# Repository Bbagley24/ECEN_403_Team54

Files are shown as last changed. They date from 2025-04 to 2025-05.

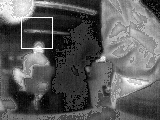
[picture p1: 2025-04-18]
website/websocket-streaming/output.png

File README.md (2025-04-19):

# **ECEN404-2025SP-Team-54**

This Repository contains all of the digital content created throughout the duration of Team 54's project. This includes the code made for the system, PCB plans and schematics, relevant presentations and documents, ect.**

- **Each subsytem has its own folder containing files and documents associated with the respective susbystem.**
- **Presentations are located in the "Presentations" folder and are organized by semester.**
- **Relevant documents are located in the "Documents and Reports" folder which is also organized by semester.**
- **All other content is stored in the "Miscellaneous" folder.**

## Overview

As industry demand grows, space inside medium voltage switchgear has become increasingly limited. Manufacturers are required to fit more devices and wires within the same limited space. Additionally, manufacturers are now being asked to include a remote viewing system within the switchgear to monitor a physical ground switch. This ground switch is physically blocked, by wires, from the view of the operator.

Our solution to this problem is to create a thermal remote viewing system that an operator can connect to through Wi-Fi, allowing for operators to confirm the grounding switch is either open or closed through video and automation. This will make switchgear operators jobs safer and more convenient.

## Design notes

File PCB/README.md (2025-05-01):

# PCB

This folder contains the Altium files used to fabricate the printed circuit boards for the system. This includes the schematics and PCB layouts for both the main board and the buck converters.
It also includes the file used to 3d print the case that protects the PCB.

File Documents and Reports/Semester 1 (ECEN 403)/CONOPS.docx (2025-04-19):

Remote Viewing within a High Voltage Apparatus

Blake Bagley, Julia Garcia, Erica Mathew

Concept of Operations

REVISION – Draft

14 September 2024

Concept of Operations

for

Remote Viewing within High Voltage Apparatus

Team <54>

Approved by:

_____________________________

Project Leader Date

_____________________________

Prof. Kalafatis Date

_____________________________

T/A Date

Change Record

Rev. | Date | Originator | Approvals | Description
- | 9/14/2024 | Remote Viewing within High Voltage Apparatus | | Draft Release

Table of Contents

List of Figures 4

1. Executive Summary 5

2. Introduction 5

2.1. Background 5

2.2. Overview 5

2.3. Referenced Documents and Standards 6

3. Operating Concept 6

3.1. Scope 6

3.2. Operational Description and Constraints 6

3.3. System Description 7

3.4. Modes of Operations 7

3.5. Users 7

3.6. Support 8

4. Scenario(s) 8

4.1. Ensuring State of Switchgear 8

5. Analysis 8

5.1. Summary of Proposed Improvements 8

5.2. Disadvantages and Limitations 9

5.3. Alternatives 9

5.4. Impact 9

List of Figures

Figure 1: Thermal Remote Viewing System Overview……………………….7

# 1. Executive Summary

As the industry demand grows, space within medium voltage switchgear has become increasingly limited. Manufacturers once had the luxury of allotting one device to a dedicated space, but now they must fit multiple apparatus for different functions into that same confined space. Manufacturers are additionally being asked to include safety devices within the switchgear. These safety devices are often not in areas that are easily accessible by the operator which makes visual inspection challenging. The goal of this project is to create a solution that enables operators to remotely view the safety devices inside the switchgear. This will significantly improve both safety and efficiency for the customer by providing continuous monitoring of the mechanical switches.

# 2. Introduction

This document is an introduction to our Proposed Thermal Remote Viewing System within High Voltage, a system capable of monitoring the mechanical safety switches within medium voltage switchgears. This project will allow operators to remotely confirm the state of the switchgear without putting themselves in danger.

## 2.1. Background

Currently, there is not a good system for monitoring the inside of a switchgear. Operators currently rely on a flashlight through a small window to get a view of the inside. This method is extremely inefficient because it provides very limited visibility and is unable to view regions that are covered by wires. This can also be very dangerous and can expose the operator to the dangers of high-voltage.

Our plan of creating a remote viewing system will allow operators to monitor the switchgear from a distance. Real time streaming with the use of thermal sensors will provide a comprehensive view of the switchgears. By placing thermal sensors close to the safety switches, we are able to get a visual representation of hard-to-reach areas.

## 2.2. Overview

Our system will be used to monitor safety switches within a medium voltage switchgear to check for gaps between contacts. We will use thermal sensors to create a temperature profile of the switchgear in real time. This raw thermal data from the sensor is sent to our microcontroller which converts the data into a video stream. Here we will have to perform linear interpolation to smooth the images. Our microcontroller would then send the processed data over a network via Wi–Fi. Finally we will create a website for the operators to easily interface with that displays the thermal video stream.

## 2.3. Referenced Documents and Standards

- IEEE Standard C37.20.2 IEEE Standard for Metal-Clad Switchgear
- IEEE Standard C37.04 IEEE Standard for Ratings and Requirement for AC High- Voltage Circuit Breakers with a Rated Maximum Voltage Above 1000V
- IEEE Standard C37.09 IEEE Standard Test Procedures for AC High-Voltage Circuit Breakers with Rated Maximum Voltage Above 1000 V
- ANSI C37.54 American National Standard for Alternating Current High-Voltage Circuit Breakers Applied in Metal-Enclosed Switchgear—Conformance Test Procedures
- NFPA 70E Standard for Electrical Safety in the Workplace
- NFPA 70 National Electrical Code

# 3. Operating Concept

## 3.1. Scope

The goal of this project is to create a system that allows for operators to remotely view a switch within a switchgear without opening it to ensure safe grounding. When an operator wants to see if the designated switch is open or closed, he/she will open a computer application that will connect to the microcontroller. A thermal image sensor will first capture a video of the designated switch; then the microcontroller will send that video to the application. One of the big constraints of this project is that we need to make sure that the dielectrics that are already in the switchgear still operate within industry standards. Due to budget constraints, the project will entail making this system for only one vertical tower of switchgear. We will still make this system expandable by having multiple towers connected to the application with their own dedicated sensors and microcontrollers. This system will help to make switchgear operators’ jobs much more safe and convenient.

## 3.2. Operational Description and Constraints

This system is intended to be used by switchgear operators to make sure switchgear can be safely operated. The operator should be able to open an application on a computer and connect to the switchgear he/she is operating on to see the desired switch’s state. An image will be taken by a thermal image system placed in the switchgear, which will then be sent to an application through a microcontroller for the operator to see. According to the sponsors of this project, the system must allow for the users to see the designated switch. Graphical representations are not enough for customers, and are not enough for operators to feel certain that the switchgear they are operating on is in the right state. The system must not cause the dielectrics to fail integrity tests because of the system’s addition to the switchgear. Also, no modifications will be made to the switchgear other than allowing for the ability to mount the system. The system is purely an addition to the switchgear.

## 3.3. System Description

There are three main parts of this system. The first part of this system is the thermal image sensor. This is what will create the image of the switch needed to be examined. The sensor will be placed within the switchgear at a respectful distance from the switch so that interference isn’t a problem. The second part of the system is the microcontroller. This part will configure the sensor, process the information read from the sensor, turn the information into something readable by an application, and send off the information through wi-fi. The final part of the system is an application that will take the information sent from the microcontroller and transform it into a viewable format for the operator. The system can be expanded upon by having more vertical towers connected to the application. Each vertical tower will have its own microcontroller and thermal image sensor to allow the application to connect to and view the inside of each tower.

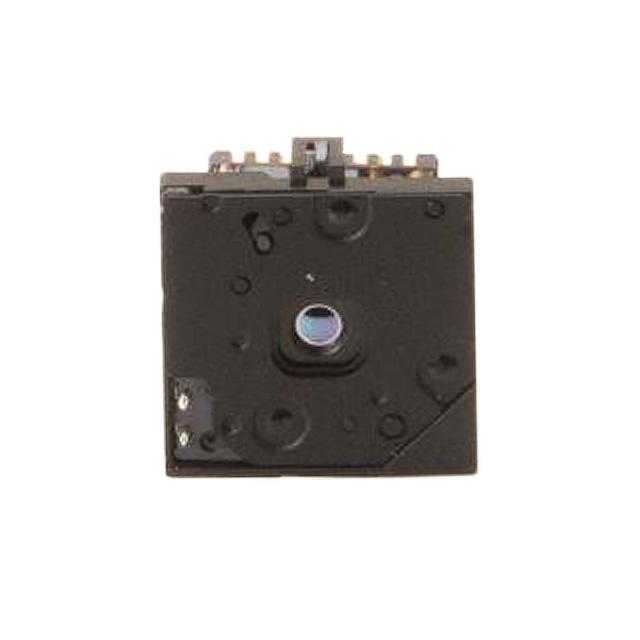
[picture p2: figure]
Figure 2
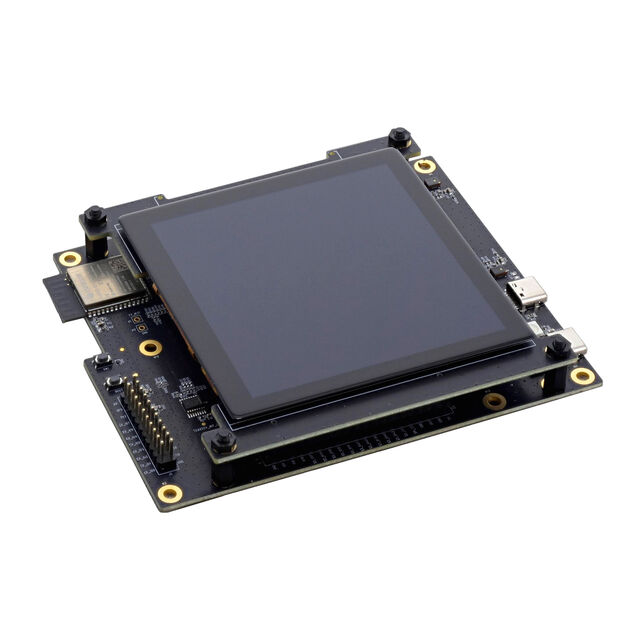
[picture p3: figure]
Figure 2
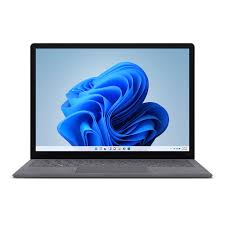
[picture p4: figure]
Figure 2

Figure 1: Thermal Remote Viewing System Overview

## 3.4. Modes of Operations

The operator only needs to view the switch through some type of produced image. The only difference between cases is that the switch might be located in a different part of the switchgear, which will cause the sensor to be placed in a new location. If this project were to be later expanded for the use of multiple towers, then this could entail the operator choosing which tower of switchgear to view.

## 3.5. Users

The users of this system, as stated throughout this report, will be switchgear operators. These operators are highly trained and knowledgeable of the hardware being observed by the proposed system. It is common for these users to have engineering and/or technical degrees. Thermal sensors are commonly used in procedures for switchgear, so operators should have some knowledge of how they work. Being that a big portion of these operators' jobs is maintenance and safety, our system will ensure that their job is much easier by giving the operator a good visualization of the state that the switchgear is in.

When it comes to the proposed system, there won't need to be any training for installation. The only training needed will probably be for the use of the application. The application should be simple to learn as it is supposed to be a tool for visualization.

## 3.6. Support

Support for our system will be given in the form of a manual on how to operate the system. It will detail the assembly of the system, configuration of the hardware, and operation of the application.

# 4. Scenario(s)

## 4.1. Ensuring State of Switchgear

The use of our thermal viewing system is to ensure the mechanical safety switches are open. If a maintenance worker needs to open up a switchgear and work inside, they can use our system to make sure it is depowered. The main problems with the switchgear are the density of electronics and lack of inner lighting. These issues make checking that the equipment is depowered extremely difficult. The operator cannot see the gaps from the window on the door, but our system will fix this. With a thermal image of the mechanical safety switches inside the switchgear, operators on the outside can visually see the open gaps, proving it is depowered and safe to open.

# 5. Analysis

## 5.1. Summary of Proposed Improvements

- The proposed system will make operating a switchgear much safer than it currently is. By having a thermal image sensor placed inside the switchgear, the system allows for the operator to not have to open up the back and check if the safety switch being observed is closed.
- The system will also utilize wi-fi which will make the switch observable at longer distances.
- The sensor can be remotely turned on and off, so the system is active only when needed by maintenance personnel. This ensures the system isn’t wasting any power.
- We could expand upon this project by making the system use machine learning. This will allow it to automatically classify switches as “open” or “closed”, which will improve the workflow for operators overseeing multiple switchgears.

## 5.2. Disadvantages and Limitations

Our proposed thermal viewing system will have some limitations which include:

- The size of the system is very limited due to the scant amount of space available within the switchgear.
- All equipment/components used in the system must be able to withstand high temperatures.
- The sensor and accompanying equipment must be shielded to ensure they don’t interfere with the dielectrics within the switchgear.
- The locations that the thermal sensor can be mounted are limited due to the space constraints within the switchgear.
- Due to budget constraints, the resolution of the picture won’t be very sharp.

## 5.3. Alternatives

Some alternatives to our proposed thermal viewing system are:

- Placing small flags behind the safety switches and using a flashlight to see inside a window on the front door of the switchgear. If the flag is visible, an operator can conclude the switches are open and the switchgear is depowered.
- Using a “normal” camera with a light source and streaming video of the switches to remote locations.
- A window placed on the backside of the switchgear closer to the mechanical safety switches. With this solution, the operator would need a light source of their own.

## 5.4. Impact

- There are no ethical concerns because the proposed system is being created to ensure the safety of anyone who works with switchgear. The system is intended to protect people at no cost to any other part of the overall switchgear.
- The environmental impact of our system is minimal. Our only impact comes from power consumption, which isn’t high.
- The impact for society would be minimal, as this wouldn’t affect the everyday lives of anyone except the operators that work directly with switchgear.

Concept of Operations Revision - Remote Viewing within High Voltage Apparatus

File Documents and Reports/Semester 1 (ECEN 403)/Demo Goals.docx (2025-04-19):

TEAM 54

Julia (PCB)

- Test #1: ESP32 Voltage

- Voltage will be read at the output of the buck converter that is wired to the ESP32.

- Criteria: The voltage read on the pcb by a multimeter will be within 5% of the simulations performed on WEBENCH.

- Test #2: VDDIO Voltage

- Voltage will be read at the output of the buck converter that is wired to the VDDIO pin of the camera.

- Criteria: The voltage read on the pcb by a multimeter will be within 5% of the simulations performed on WEBENCH.

- Test #3: VDDC Voltage

- Voltage will be read at the output of the buck converter that is wired to the VDDC pin of the camera.

- Criteria: The voltage read on the pcb by a multimeter will be within 5% of the simulations performed on WEBENCH.

- Test #4: VDD Voltage

- Voltage will be read at the output of the buck converter that is wired to the VDD pin of the camera.

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

- Test #5: Data Flow

- Using the oscilloscope, data flow will be read between the ESP32 and the camera.

- Criteria: There must be a waveform proving data is being transferred to the ESP32 from the camera.

Blake (Microcontoller)

- Test #1: WiFi Connection

- Microcontroller’s SSID will be seen over WiFi on any Laptop

- Test #2: Image Processing

- Example photo data will be processed to show accuracy

- Test #3: Receiving Image Data

- ESP-IDF command prompt will have a VoSPI packet printed in byte values to show accurate reception

Erica (Web Application)

- Test #1: Login Page/ Registration page

- When a user registers a new account it must show up in firebase. Incorrect login information should output an error message. Correct login information should direct the user to the overview page.

- Test #2: Overview page directs to correct “video stream”

- When the user clicks on a specific Model ID it should direct them to its respective video stream

- Test #3: Fetching Images

- Website properly fetches images in series and outputs the latest one at a rapid pace.

- Test #4: Drag and Drop UI works

- The user should be able to drag and drop boxes that represent the model IDs. When the user clicks on a specific box it should direct them to its respective video stream.

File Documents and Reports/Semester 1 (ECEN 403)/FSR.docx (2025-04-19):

Remote Viewing within a High Voltage Apparatus

Blake Bagley, Julia Garcia, Erica Mathew

Functional System Requirements

REVISION – Draft

24 September 2024

Functional System Requirements

for

Remote Viewing within a High Voltage Apparatus

Prepared by:

_____________________________

Author Date

Approved by:

_____________________________

Project Leader Date

_____________________________

John Lusher, P.E. Date

_____________________________

T/A Date

Change Record

Rev. | Date | Originator | Approvals | Description
- | 9/26/2024 | Remote Viewing within High Voltage Apparatus | | Draft Release

Table of Contents

Table of Contents III

List of Tables IV

No table of figures entries found. IV

List of Figures V

1. Introduction 5

1.1. Purpose and Scope 5

1.2. Responsibility and Change Authority 6

2. Applicable and Reference Documents 8

2.1. Applicable Documents 8

2.2. Reference Documents 8

2.3. Order of Precedence 9

3. Requirements 9

3.1. System Definition 9

3.2. Characteristics 10

3.2.1. Functional / Performance Requirements 10

3.2.2. Physical Characteristics 10

3.2.3. Electrical Characteristics 12

3.2.4. Environmental Requirements 13

3.2.5. Failure Propagation 13

4. Support Requirements 13

List of Tables

Table 1: Responsibilities ……………..……………………………………………………………..6

Table 2: Applicable Documents …………..………………………………………………………..8

Table 1: Reference Documents ………………………………..…………………………………..8

List of Figures

Figure 1. Conceptual Image……………………………………………………………………...6

Figure 2. Block Diagram of System…………………………………………………………..9

# 1. Introduction

## 1.1. Purpose and Scope

As industry demand grows, space inside medium voltage switchgear has become increasingly limited. Manufacturers are required to fit more devices and wires within the same limited space. Additionally, manufacturers are now being asked to include a remote viewing system within the switchgear to monitor a physical ground switch. This ground switch is physically blocked, by wires, from the view of the operator. Our project, Thermal Remote Viewing System within High Voltage, provides a real time visual depiction of the ground switch that an operator can view from a safe distance away from the switchgear. We will use a thermal sensor to create an image of the ground switch, which will then be sent to the microcontroller to process the information into a viewable format. The video information will then be sent to a web application for the operator to interface with. Our system will increase safety and efficiency for switchgear operators.

Figure 1. Conceptual Image

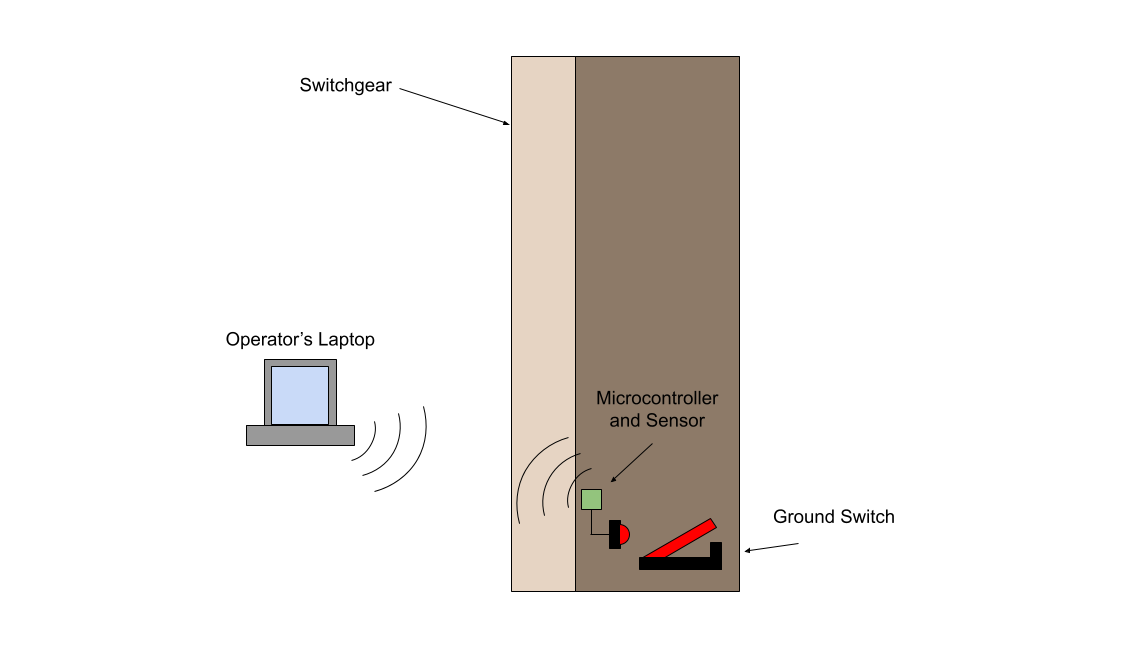
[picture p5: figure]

## 1.2. Responsibility and Change Authority

Erica Mathew will make sure all requirements detailed in the Functional System Requirements will be met. Requirements can only be changed if Erica and our sponsors at Powell Industries approve of the changes. Below are the responsibilities of everyone in the team.

Subsystem | Responsibility
Thermal Image Sensor | Julia Garcia
Microcontroller | Blake Bagley
Web Application | Erica Mathew

# 2. Applicable and Reference Documents

## 2.1. Applicable Documents

The following documents, of the exact issue and revision shown, form a part of this specification to the extent specified herein:

Document Number | Revision/Release Date | Document Title
IEEE Standard C37.20.2 | 2015-09-22 | IEEE Standard for Metal-Clad Switchgear
IEEE Standard C37.04 | 2019-05-31 | IEEE Standard for Ratings and Requirement for AC High- Voltage Circuit Breakers with a Rated Maximum Voltage Above 1000V
IEEE Standard C37.09 | 2019-04-11 | IEEE Standard Test Procedures for AC High-Voltage Circuit Breakers with Rated Maximum Voltage Above 1000 V
ANSI C37.54 | 2023 | American National Standard for Alternating Current High-Voltage Circuit Breakers Applied in Metal-Enclosed Switchgear—Conformance Test Procedures
NFPA 70E | 2024 | Standard for Electrical Safety in the Workplace
NFPA 70 | 2023 | National Electrical Code

## 2.2. Reference Documents

The following documents are reference documents utilized in the development of this specification. These documents do not form a part of this specification and are not controlled by their reference herein.

Document Number | Revision/Release Date | Document Title
1 | Version 1.9 | ESP32-S3 Series Datasheet
2 | Revision 204 | FLIR LEPTON® Engineering Datasheet
3 | 12/22/2020 | GlobTek, Inc. Li-Ion Polymer 3.7 V Battery Pack

## 2.3. Order of Precedence

In the event of a conflict between the text of this specification and an applicable document cited herein, the text of this specification takes precedence without any exceptions.

All specifications, standards, exhibits, drawings or other documents that are invoked as “applicable” in this specification are incorporated as cited. All documents that are referred to within an applicable report are considered to be for guidance and information only, except ICDs that have their relevant documents considered to be incorporated as cited.

# 3. Requirements

## 3.1. System Definition

The Thermal Remote Viewing System within High Voltage is a system specifically designed for remotely monitoring ground switches within a medium voltage switchgear. It allows operators to confirm a vertical tower is properly grounded before opening the switchgear. This system provides a real-time video stream of the ground switches which will be broadcasted to an online website. Our system consists of a thermal image sensor, microcontroller and a website.

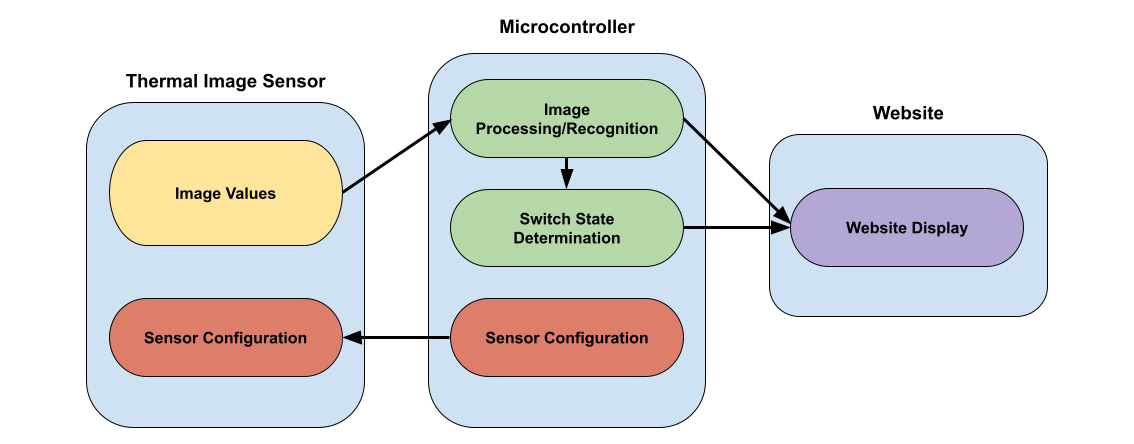
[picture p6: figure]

Figure 2. Block Diagram of System

There are three main components to this system. First block represents the first main component which is the thermal image sensor. This sensor will take in IR values and turn them into an image for the microcontroller to process. This sensor will need to be configured to be in the image format that will be used by the microcontroller.

The second block which is the microcontroller will use a machine learning algorithm to determine where the switch is located and another algorithm will be used for determining if the grounding switch is open or closed. The video and switch state will be then sent from the microcontroller to the website to be viewed by the operator.

## 3.2. Characteristics

### 3.2.1. Functional / Performance Requirements

#### 3.2.1.1. Connection to Website

The Thermal Remote Viewing System shall allow for multiple microcontrollers and thermal image sensors in different vertical towers to be connected to the website.

Rationale: This will allow for the operator to view multiple vertical towers.

#### 3.2.1.2. Machine Learning Error Rate

The Image Recognition and Switch State Determination done by the microcontroller shall not have an error rate exceeding 10%.

Rationale: This will allow for the machine learning of the microcontroller to perform as accurately as needed.

#### 3.2.1.3. Thermal Sensor Node Area

The thermal sensors should take a visual image that covers a minimum viewable area of 6x6 inches.

Rationale: This is a requirement specified by our customer to properly see the gap between contacts in the ground switches.

#### 3.2.1.4. Video Latency

The video output shall be a live video stream with no more than a 5 second delay.

Rationale: This is a requirement specified by our customer to properly view the gap between contacts in the ground switches.

#### 3.2.1.5. Video Resolution

The video output shall have a pixel resolution of 160x120 pixels

Rationale: This is the resolution of the thermal sensor we chose. This will allow for a clear image for the operator to observe.

### 3.2.2. Physical Characteristics

#### 3.2.2.1. Volume Envelope

The volume envelope of the Remote System shall be less than or equal to 6 inches in height, 6 inches in width, and 6 inches in length.

Rationale: This is a requirement specified by our customer due to constraints of the switchgear the system will be operating in

#### 3.2.2.2. Mounting

The thermal sensor should be mounted facing the ground switches to allow for a complete view. The mounting information shall be captured in the Remote Viewing System within High Voltage ICD.

Rationale: This is a requirement specified by our customer to provide a clear image to the operator.

#### 3.2.2.3. Installation

The installation information for The Thermal Remote Viewing System within High Voltage shall be provided to the customer through a user manual.

### 3.2.3. Electrical Characteristics

#### 3.2.3.1. Inputs

b. No inputs of the operator shall inhibit the function of The Thermal Remote Viewing System.

Rationale: By design, this should limit the risk of the system becoming damaged.

##### 3.2.3.1.1 Power Consumption

a. The maximum peak power of the system shall not exceed 3 watts.
b. For our class demonstration we will use a battery pack to power our system. If this system were to be adopted into a switchgear, it shall pull power from the switchgear itself.

Rationale: This is specified by the ESP32-S3 Series Datasheet and FLIR LEPTON® Engineering Datasheet.

##### 3.2.3.1.2 Input Voltage Level

The input voltage level for the Search and Rescue System shall be +3.7 VDC to +4.2 VDC.

Rationale: This is specified by GlobTek, Inc. Li-Ion Polymer 3.7 V Battery Pack Datasheet

#### 3.2.3.2. Outputs

##### 3.2.3.2.1 Data Output

The Thermal Remote Viewing System within High Voltage shall include an website interface compatible with the microcontroller to view the ground switch.

Rationale: The Thermal Remote Viewing System within High Voltage information passes directly to the customer’s system.

##### 3.2.3.2.2 Raw Video Output

The Thermal Remote Viewing System shall output a RAW14 video for the operator to view on the system’s website.

Rationale: This is a requirement specified in the FLIR LEPTON® Engineering Datasheet.

#### 3.2.3.3. Connectors

The Thermal Remote Viewing System within High Voltage shall follow the America National Standard for Electrical Connectors ANSI C119.6-2011.

Rationale: This is a requirement specified by in accordance with our battery

### 3.2.4. Environmental Requirements

The Thermal Remote Viewing System shall be designed to withstand and operate in the environments and laboratory tests specified in the following section.

Rationale: This is a requirement specified by our customer due to constraints of their system in which the The Thermal Remote Viewing System is integrating.

##### 3.2.4.1. Thermal Resistance

The Thermal Remote Viewing System should be able to properly operate in an environmental temperature up to 80C.

Rationale: This is a requirement specified in the FLIR LEPTON® Engineering Datasheet.

##### 3.2.4.1.1 Dielectrics Test

The Thermal Remote Viewing System shall not compromise the integrity of the dielectrics already within the switchgear

### 3.2.5. Failure Propagation

If the website doesn’t receive video input from the microcontroller after 30 seconds, the website shall display a notice that there is a problem connecting to the microcontroller.

Rationale: This will allow for the user to know if something is wrong with the system.

# 4. Support Requirements

The Thermal Remote Viewing System shall require internet connection and a computer in order to interact with the website application.

Functional System Requirements Revision - Remote Viewing within a High Voltage Apparatus

Functional System Requirements Revision - Project Name

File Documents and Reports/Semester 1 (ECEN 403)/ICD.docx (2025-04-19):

Remote Viewing within a High Voltage Apparatus

Blake Bagley, Julia Garcia, Erica Mathew

Interface Control Document

REVISION – Draft

26 September 2024

Interface Control Document

for

Remote Viewing within a High Voltage Apparatus

Prepared by:

_____________________________

Author Date

Approved by:

_____________________________

Project Leader Date

_____________________________

John Lusher II, P.E. Date

_____________________________

T/A Date

Change Record

Rev. | Date | Originator | Approvals | Description
- | 9/26/2024 | Blake Bagley, Julia Garcia, Erica Mathew | | Draft Release

Table of Contents

Table of Contents III

List of Tables IV

List of Figures V

1. Overview 6

2. References and Definitions 6

2.1. References 6

2.2. Definitions 6

2.3. Referenced Documents and Standards 6

3. Physical Interface 6

3.1. Weight 6

3.2. Dimensions 7

3.3. Mounting Locations 7

4. Thermal Interface 7

5. Electrical Interface 8

5.1. Primary Input Power 8

5.2. Voltage and Current Levels 8

5.3. Data Interfaces 9

5.4. User Control Interface 9

6. Communication/Device Interface 9

6.1. Wireless Communications 9

List of Tables

Table 1: Printed Circuit Board Weight……………………………………………………………..5

Table 2: Printed Circuit Board Dimensions………………………………………………………..6

Table 3: Maximum Voltage, Current and Power Levels………………………………………….7

Table 4: Nominal Voltage, Current and Power Levels…………………………………………...8

List of Figures

Figure 1: Electrical Interface Diagram………………………………………………………7

# 1. Overview

This document is provided to detail how the thermal sensor will interface with the microcontroller and how the microcontroller will interface with the website. It will list all inputs, outputs, and how the system manages each. An explanation of the inputs from the thermal sensor to the microcontroller will be provided. Then, an explanation of how that input will be transferred from the microcontroller to the website will follow.

# 2. References and Definitions

## 2.1. References

Refer to section 2.2 of the Functional System Requirements document.

## 2.2. Definitions

mA Milliamp

mW Milliwatt

g Grams

mm Millimeters

V Volts

TBD To Be Determined

# 3. Physical Interface

## 3.1. Weight

3.1.1. Entire Printed Circuit Board

Component | Weight | Number of Items | Total Weight
FLIR Lepton 3.5 Thermal Sensor | 0.91 g | 1 | 0.91 g
ESP32-S3 | TBD | 1 | TBD
Buck Converter Circuitry | TBD | 4 | TBD

Table 1: Printed Circuit Board Weight

## 3.2. Dimensions

### 3.2.1. Dimensions of Entire Printed Circuit Board

Component | Length | Width | Height
FLIR Lepton 3.5 Thermal Sensor | 12.7 mm | 11.5 mm | 6.835 mm
ESP32-S3 | 7 mm | 7 mm | 0.85 mm
Buck Converter Circuitry | TBD | TBD | TBD

Table 2: Printed Circuit Board Dimensions

## 3.3. Mounting Locations

The thermal sensor will be mounted facing the grounding switch at the back of the switchgear. The sensor must face the grounding switch because the switch is being viewed by the operator. It can only fit in the back due to space constraints within the switchgear.

# 4. Thermal Interface

The ESP-32 microcontroller will use a heat sink in order to prevent overheating and decreased efficiency. There is only one microcontroller in our system, so only one heat sink is needed. The thermal sensor has safeguards in place to prevent overheating.

# 5. Electrical Interface

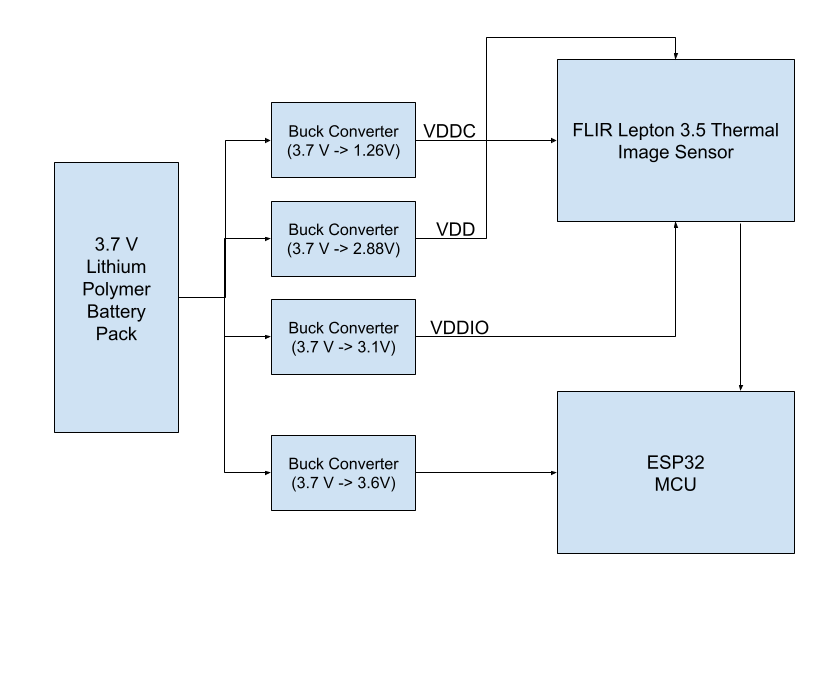
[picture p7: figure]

Figure 1: Electrical Interface Diagram

## 5.1. Primary Input Power

The system will be battery powered using a rechargeable 3.7 V lithium-ion polymer battery. When implemented into the switchgear, the system will be powered by the switchgear itself.

## 5.2. Voltage and Current Levels

### 5.2.1. Maximum Values

Component | Voltage [V] | Current [mA] | Power [mW]
FLIR Lepton 3.5 Thermal Sensor | 4.8 | 16 | 76.8
FLIR Lepton 3.5 Thermal Sensor Core | 1.5 | 110 | 165
FLIR Lepton 3.5 Thermal Sensor I/O | 4.8 | 310 | 1488
ESP32-S3 | 3.6 | 1500 | 3600

Table 3: Maximum Voltage, Current and Power Levels

### 5.2.2. Nominal Values

Component | Voltage [V] | Current [mA] | Power [mW]
FLIR Lepton 3.5 Thermal Sensor | 2.8 | 14 | 39.2
FLIR Lepton 3.5 Thermal Sensor Core | 1.2 | 84 | 100.8
FLIR Lepton 3.5 Thermal Sensor I/O | 3.1 | 235 | 728.5
ESP32-S3 | 3.3 | 500 | 1650

Table 4: Nominal Voltage, Current, and Power Levels

## 5.3. Data Interfaces

The thermal sensor will send raw video data to the microcontroller through serial pins (SPI), both the sensor and microcontroller are mounted to the PCB.

## 5.4. User Control Interface

The user control interface is a website that communicates with the microcontroller. The user will login using credentials provided through their companies. Then, the user will be able to select what switchgear vertical tower will be viewed. The user can select the desired video stream from the overview page or the user can use the search bar to find their desired video stream.

# 6. Communications / Device Interface Protocols

## 6.1. Wireless Communications

### 6.1.1. Wi-Fi

The microcontroller has a built-in WiFi module using IEEE 802.11b/g/n standards. This connection will be used to stream live video to the operator’s website.

Remote Viewing within a High Voltage Apparatus Revision -

Interface Control Document Revision - Remote Viewing within a High Voltage Apparatus

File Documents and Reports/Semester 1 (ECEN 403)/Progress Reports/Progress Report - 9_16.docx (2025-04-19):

Subsystem 1 - Julia (9/16)

- As a team we decided on the microcontroller and sensor we are using
  - Sensor: THERMAL IMAGE SENSOR 160HX120V
  - Microcontroller: ESP32
- Researched the viability of fiber optic cables to transfer data, not viable
- Researched how to encase the sensor and accompanying pcb, so the switchgear can pass the dielectric test.
  - A thin plastic material should work as it won’t interfere with the thermal sensor and isn’t metal
- Requested Altium access -> gained Altium access
- Created the github repository
- Researched possible power supplies, need at least 3.1 volts to power chosen sensor
  - GB20S05K01 - AC/DC CONVERTER 5V 15W ($8)
  - IRM-15-5 - Enclosed AC DC Converters 1 Output 5V 3A 85 ~ 305 VAC, 120 ~ 430 VDC Input ($9.28)
  - PAAM15-10 - Enclosed AC DC Converters 1 Output 5V 3A 90 ~ 264 VAC, 120 ~ 370 VDC Input ($20.59)
  - All three meet voltage requirements, PAAM has the best temperature rating with a max operating temp of 80 C, the other two have a max of 70 C.
    - Over double the price might not be worth only a 10 degree increase
- Researched how to plot a heatmap on matlab
  - https://www.mathworks.com/help/bioinfo/ref/heatmap.view.html
- Plan to order parts this week, so we can begin testing asap
- Set up Altium and start the subsystem project, goal is to finish
- For demo: Uart-usb then process in matlab

Subsystem 2-v

Subsystem 3-Erica (9/16)

- Started Researching website developments and built basic html layout that shows the video streaming feed
  - It currently displays an empty video and drop down to view different switchgear #’s
- Researching API for fetching videos
- Brainstorming new website features to be implemented:

Next steps:

- Make it look nice, put in powell colors/font
- Have login screen to input employee ID (requires database)
- Have search for switchgear serial code, once it pulls up it will display adjacent switchgears in drop down format (so operator does not have to retype code for switchgear right next to the original one)

9/23 Erica

- Completed Subsystem Introduction Project
- Continued working on Website UI design
- Met with company to discuss project requirements
- Started working on FSR and ICD

Blake (9/16)

* Dev microcontroller has been received

* Looking into frameworks and methods of ML to use

* Will probably use TensorFlow to identify the switch and use my own pixel math to determine if the switch is open or closed.

* More recently started on intro project

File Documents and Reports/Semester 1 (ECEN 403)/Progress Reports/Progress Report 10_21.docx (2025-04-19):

Erica:

Completed:

- Created a server using websockets to read images from a folder and outputs to a client (browser)
  - Using a 1000 image zip file the ‘video stream’ cycles through the images as it will with the microcontroller. Currently cycling as one image per second, but I will increase it.

Next Steps:

- Creating a ‘map page’ which is a buildable map for users to drag/drop blocks to match the physical layout of their switchgear setup.

Julia:

Completed:

- Finished the schematics for buck converters and overall pcb.

Next Steps:

- Currently routing the pcb, will be done by end of week
- Design review by end of week -> order the pcb

Blake:

Completed:

- Switch-State Determination done
- ESP32 can connect to devices through WiFi (very rough draft version)

Next Steps:

- Start coding for thermal sensor
- Create outline for image processing

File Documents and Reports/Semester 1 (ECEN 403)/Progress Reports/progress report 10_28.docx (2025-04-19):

Erica (out sick with excused absence):

Completed:

- Almost completed drag and drop buildable map **add image**
- Demo with 1000 image zip file is working

Next Steps:

- Clean up map, make it sleeker
- Add additional features to website

Julia:

Completed:

- Pcb is complete and ordered
- All parts not ordered have been acquired from the cage

Next Steps:

- Once it arrives begin soldering components and begin testing

Blake:

Completed:

- Have SPI communication set up for camera (not verified yet)

Next Steps:

- Test SPI communication
- Make SPI code turn a stream into a frame of data

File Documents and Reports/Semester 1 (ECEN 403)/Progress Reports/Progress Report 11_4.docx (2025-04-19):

Julia

- PCB arrived
- This week:
  - Start soldering

Blake

- VoSPI (data collection) is close to done, it is a little inaccurate with timing at times
- Still waiting on Powell to send photos to determine which rows and what temperatures to use for processing

This Week:

- Get code for processing image done (with or without photos)
- Efficiently storing data

Erica

- Finished drag/drop map
- This week:
  - Cleaning up functionality/look
  - Adding more features

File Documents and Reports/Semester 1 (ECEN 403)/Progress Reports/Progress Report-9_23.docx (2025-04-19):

9/23 Julia

- Chose power supply: 3.7 Lithium Polymer Battery Pack from GlobTek Inc.
- Order parts today (connectors, battery pack, enclosure material sheet and sensor)
- Finished block diagram for the circuits
- Start designing buck converters, need at least 4
  - VDDC pin for sensor (core voltage)
  - VDDIO pin for sensor (I/O voltage)
  - VDD pin for sensor (sensor voltage)
  - Input voltage for MCU
- Enclosure material chosen
  - UHMW (ultra-high molecular weight) polyethylene
  - Need to decide on thickness - can’t exceed 6 inches
    - Could have thinner piece where sensor points and thicker around the rest of the pcb

9/23 Erica

- Completed Subsystem Introduction Project
- Continued working on Website UI design
- Met with company to discuss project requirements
- Started working on FSR and ICD

Blake (9/23)

* Dev microcontroller has been received

* Looking into frameworks and methods of ML to use

* Will probably use TensorFlow to identify the switch and use my own pixel math to determine if the switch is open or closed.

* More recently started on intro project

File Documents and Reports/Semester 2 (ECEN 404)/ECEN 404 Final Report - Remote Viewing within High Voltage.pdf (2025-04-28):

## Remote Viewing Within High Voltage Apparatus

## Blake Bagley Julia Garcia Erica Mathew

# Remote Viewing Within High Voltage Apparatus Final Report

## Table of Contents

## Schedule and Validation 4

Concept of Operations | 7
Table of Contents | 10
List of Figures | 11

### 1. Executive Summary 12 2. Introduction 12 3. Operating Concept 13 4. Scenario(s) 15

5. Analysis | 16
Functional System Requirements | 18
Table of Contents | 21
List of Tables | 22
List of Figures | 23
6. Introduction | 24
7. Applicable and Reference Documents | 25
8. Requirements | 27
9. Support Requirements | 31
Interface Control Document | 30
Table of Contents | 35
List of Tables | 36
List of Figures | 37
10. Overview | 38

### 11. References and Definitions 38 12. Physical Interface 38 13. Thermal Interface 39 14. Electrical Interface 40

15.Communication/Device Interface 41

## Subsystem Reports 42

Table of Contents | 45
List of Figures | 46

### 16. Introduction 47 17. Thermal Sensor/PCB Subsystem Report 47

18.Microcontroller Subsystem Report | 52
19. Web Interface Subsystem Report | 61

## System Report 68

Table of Contents | 71
List of Figures | 72
20. Overview | 72
21.Development Plan and Execution 73 22.Conclusion 76

## Remote Viewing Within High Voltage Apparatus

## Blake Bagley Julia Garcia Erica Mathew

# Schedule and Validation

REVISION – 3
26 April 2025

Schedule

Validation

Test Name | Success Criteria | Methodology | Status | Engineers
Input Voltage | Voltage powering the PCB should be ~3.7 Volts. | Use multimeter to measure the DC voltage. | PASSED | Julia
Converter Voltage | Buck converter providing voltage should output ~3.3 Volts. | Use multimeter to measure the DC voltage. | PASSED | Julia
Board Communication | ESP32 should receive data from camera | Use oscilloscope to measure the data stream. | PASSED | Julia
Microcontroller connects to website | Website successfully received an HTTP POST request from the ESP32. | Checking the console log of both the website and microcontroller. | PASSED | Erica + Blake
Microcontroller sending image data | The website successfully received raw image data. | Checking console log on website and converting the raw image data to a png. | PASSED | Erica + Blake
Switch State Determination | The microcontroller should be able to identify the Switch State of a makeshift switch. | The microcontroller will monitor a box with a body heat source to demonstrate switch state determination. | PASSED | Blake
Dielectrics Test | The PCB should pass the dielectrics test and not cause any interference with the switchgear. | This will be tested at POWELL Industries. | PASSED | Julia
Switch State Determination Display | The website should be able to accurately display the Switch State Determination. | Switch State Determination with a makeshift switch. | PASSED | Erica + Blake
Website can load and display images in real time | The website should be able to display a few frames per second to mimic a slow video stream. | When the camera is running, the operator will monitor the latency on the website. | PASSED | Erica + Blake
Website is functioning as expected | The Login/Registration pages, Overview page, Map Builder page, and Video page are properly working. | The user will go through the components of the website and confirm it’s working properly. | PASSED | Erica

## Remote Viewing Within High Voltage Apparatus

## Blake Bagley Julia Garcia Erica Mathew

# Concept of Operations

REVISION – 3
26 April 2025

Concept of Operations
Remote Viewing within High Voltage Apparatus | Revision - 3

### CONCEPT OF OPERATIONS

### FOR

## Remote Viewing within High Voltage Apparatus

TEAM 54

APPROVED BY:

__________________________________
Project Leader | Date

__________________________________
Prof. Kalafatis | Date

__________________________________
T/A | Date

Concept of Operations

Change Record

Rev. | Date | Originator | Approvals | Description
1 | 12/5/2024 | Erica Mathew | | Draft Release
2 | 4/2/2025 | Julia Garcia | | April Update
3 | 4/26/2025 | Julia Garcia | | Final Release

Concept of Operations

Table of Contents

Table of Contents 10
List of Figures | 11
1. Executive Summary | 12
2. Introduction | 12
2.1. Background 12
2.2. Overview 12
2.3. Referenced Documents and Standards 13
3. Operating Concept | 13
3.1. Scope | 13
3.2. Operational Description and Constraints | 14
3.3. System Description | 14
3.4. Modes of Operation | 15
3.5. Users | 15
3.6. Support | 15
4. Scenarios(s) | 15
4.1. Ensuring State of Switchgear | 15
5. Analysis | 16
5.1. Summary of Proposed Improvements | 16
5.2. Disadvantages and Limitations | 16
5.3. Alternatives | 16
5.4. Impact | 17

Concept of Operations

List of Figures

Figure 1: Remote Thermal Viewing System Overview | 14

Concept of Operations

### 1. Executive Summary

As industry demand grows, space within medium voltage switchgear has become increasingly limited. Manufacturers once had the luxury of allotting one device to a dedicated space, but now they must fit multiple apparatus for distinct functions into that same confined space. Manufacturers are additionally being asked to include safety devices within the switchgear. These safety devices are often not in areas that are easily accessible by the operator which makes visual inspection challenging. The goal of this project is to create a solution that enables operators to remotely view the safety devices inside the switchgear. This will significantly improve both safety and efficiency for the customer by providing continuous monitoring of the mechanical switches.

### 2. Introduction

This document is an introduction to our Proposed Thermal Remote Viewing System within High Voltage, a system capable of monitoring the mechanical safety switches within medium voltage switchgears. This project will allow operators to remotely confirm the state of the switchgear without putting themselves in danger.

### 2.1. Background

Currently, there is not a good system for monitoring the inside of a switchgear. Operators currently rely on a flashlight through a small window to get a view of the inside. This method is extremely inefficient because it provides extremely limited visibility and is unable to view regions that are covered by wires. This can also be extremely dangerous and can expose the operator to the dangers of high voltage.
Our plan of creating a remote viewing system will allow operators to monitor the switchgear from a distance. Real time streaming with the use of thermal sensors will provide a comprehensive view of the switchgears. By placing thermal sensors close to the safety switches, we are able to get a visual representation of hard-to-reach areas.

### 2.2. Overview

Our system will be used to monitor safety switches within a medium voltage switchgear to check for gaps between contacts. We will use thermal sensors to create a temperature profile of the switchgear in real time. This raw thermal data from the sensor is sent to our microcontroller which converts the data into an image stream. Here we will have to perform linear interpolation to smooth the images. Our microcontroller would then send the processed data over a network via Wi-Fi. Finally, we will create a website for the operators to easily interface with that displays the thermal image stream.

Concept of Operations

### 2.3. Referenced Documents and Standards

- IEEE Standard C37.20.2 IEEE Standard for Metal-Clad Switchgear
- IEEE Standard C37.04 IEEE Standard for Ratings and Requirement for AC High-Voltage Circuit Breakers with a Rated Maximum Voltage Above 1000V
- IEEE Standard C37.09 IEEE Standard Test Procedures for AC High-Voltage Circuit Breakers with Rated Maximum Voltage Above 1000 V
- ANSI C37.54 American National Standard for Alternating Current High-Voltage Circuit Breakers Applied in Metal-Enclosed Switchgear—Conformance Test Procedures
- NFPA 70E Standard for Electrical Safety in the Workplace
- NFPA 70 National Electrical Code

### 3. Operating Concept

### 3.1. Scope

The goal of this project is to create a system that allows operators to remotely view a switch within a switchgear without opening it to ensure safe grounding. When an operator wants to see if the designated switch is open or closed, he/she will open a computer application that will connect to the microcontroller. A thermal image sensor will first capture an image of the designated switch; then the microcontroller will send that image to the application. One of the big constraints of this project is that we need to make sure that the dielectric integrity within the switchgear still meets industry standards. Due to budget constraints, the project will entail making this system for only one vertical tower of switchgear. We will still make this system expandable by having multiple towers connected to the application with their own dedicated sensors and microcontrollers. This system will help to make switchgear operators’ jobs much safer and more convenient.

Concept of Operations

### 3.2. Operational Description and Constraints

This system is intended to be used by switchgear operators to make sure switchgear can be safely operated. The operator should be able to open an application on a computer and connect to the switchgear he/she is operating on to see the desired switch’s state. An image will be taken by a thermal image system placed in the switchgear, which will then be sent to an application through a microcontroller for the operator to see.
According to the sponsors of this project, the system must allow the users to see the designated switch. Graphical representations are not enough for customers and are not enough for operators to feel certain that the switchgear they are operating on is in the right state. The system must not cause the dielectrics to fail integrity tests due to the system’s addition to the switchgear. Also, no modifications will be made to the switchgear other than allowing for the ability to mount the system. The system is purely an addition to the switchgear.

### 3.3. System Description

There are three main parts of this system. The first part of this system is the thermal image sensor. This is what will create the image of the switch needed to be examined. The sensor will be placed within the switchgear at a reasonable distance from the switch so that interference isn’t a problem. The second part of the system is the microcontroller. This part will configure the sensor, process the information read from the sensor, turn the information into something readable by an application, and send off the information through wi-fi. The final part of the system is an application that will take the information sent from the microcontroller and transform it into a viewable format for the operator. The system can be expanded upon by having more vertical towers connected to the application. Each vertical tower will have its own microcontroller and thermal image sensor to allow the application to connect to and view the inside of each tower.

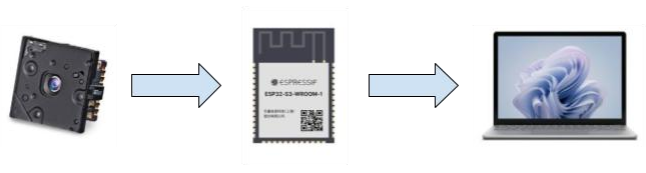
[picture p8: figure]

Figure 1: Remote Thermal Viewing System Overview

Concept of Operations

### 3.4. Modes of Operation

The operator only needs to view the switch through some type of produced image. The only difference between cases is that the switch might be located in a different part of the switchgear, which will cause the sensor to be placed in a new location. If this project were to be later expanded for use in multiple towers, then this could entail the operator choosing which tower of switchgear needs to view on the website.

### 3.5. Users

The users of this system, as stated throughout this report, will be switchgear operators. These operators are highly trained and knowledgeable of the hardware being observed by the proposed system. It is common for these users to have engineering and/or technical degrees. Thermal sensors are commonly used in procedures for switchgear, so operators should have some knowledge of how they work. Being that a substantial portion of these operators' jobs are maintenance and safety, our system will ensure that their job is much easier by giving the operator a good visualization of the state that the switchgear is in. When it comes to the proposed system, there won't need to be any training for installation. The only training needed will be for the use of the application. The application should be simple to learn as it is supposed to be a tool for visualization.

### 3.6. Support

Support for our system will be given in the form of a manual on how to operate the system. It will detail the assembly of the system, configuration of the hardware, and operation of the application.

### 4. Scenario(s)

### 4.1. Ensuring State of Switchgear

The use of our thermal viewing system is to ensure the mechanical safety switches are open. If a maintenance worker needs to open up a switchgear and work inside, they can use our system to make sure it is not powered. The main problems with the switchgear are the density of electronics and lack of inner lighting. These issues make checking that the equipment is depowered extremely difficult. The operator cannot see the gaps from the window on the door, but our system will fix this. With a thermal image of the mechanical safety switches inside the switchgear, operators on the outside can visually see the open gaps, proving it is depowered and safe to open.

Concept of Operations

### 5. Analysis

### 5.1. Summary of Proposed Improvements

- The proposed system will make operating a switchgear much safer than it currently is. By having a thermal image sensor placed inside the switchgear, it is no longer necessary for the operator to open the back of the switchgear to check the status of the safety switch.
- The system will also utilize wi-fi which will make the switch observable from longer distances.
- We could expand upon this project by making the system use machine learning. This will allow it to automatically classify switches as “open” or “closed,” which will improve the workflow for operators overseeing multiple switchgears.

### 5.2. Disadvantages and Limitations

Our proposed thermal viewing system will have some limitations which include:

- The size of the system is extremely limited due to the scant amount of space available within the switchgear.
- All equipment/components used in the system must be able to withstand high temperatures.
- The sensor and accompanying equipment must be shielded to ensure they don’t interfere with the dielectrics within the switchgear.
- The locations where the thermal sensor can be mounted are limited due to the space constraints within the switchgear.
- Due to budget constraints, the resolution of the picture won’t be very sharp.

### 5.3. Alternatives

Some alternatives to our proposed thermal viewing system are:

- Placing small flags behind the safety switches and using a flashlight to see inside a window on the front door of the switchgear. If the flag is visible, an operator can conclude the switches are open and the switchgear is depowered.
- Using a “normal” camera with a light source and streaming video of the switches to remote locations.
- A window placed on the backside of the switchgear closer to the mechanical safety switches. With this solution, the operator would need a light source of their own.

Concept of Operations

### 5.4. Impact

- There are no ethical concerns because the proposed system is being created to ensure the safety of anyone who works with switchgear. The system is intended to protect people at no cost to any other part of the overall switchgear.
- The environmental impact of our system is minimal. Our only impact comes from power consumption, which isn’t high.
- The societal impact would be minimal, as this would only affect the everyday lives of the operators that work directly with switchgear.

## Remote Viewing Within High Voltage Apparatus

## Blake Bagley Julia Garcia Erica Mathew

# Functional System Requirements

REVISION – 3
26 April 2025

Functional System Requirements

### FUNCTIONAL SYSTEM REQUIREMENTS

### FOR

## Remote Viewing within High Voltage Apparatus

TEAM 54

APPROVED BY:

__________________________________
Project Leader | Date

__________________________________
Prof. Kalafatis | Date

__________________________________
T/A | Date

Functional System Requirements

Change Record

Rev. | Date | Originator | Approvals | Description
1 | 12/5/2024 | Erica Mathew | | Draft Release
2 | 4/2/2025 | Julia Garcia | | April Update
3 | 4/26/2025 | Julia Garcia | | Final Release

Functional System Requirements

Table of Contents

Table of Contents 21
List of Tables | 22
List of Figures | 23
6. Introduction | 24
6.1. Purpose and Scope | 24
6.2. Responsibility and Change Authority | 25
7. Applicable and Reference Documents | 25
7.1. Applicable Documents | 25
7.2. Reference Documents | 25
7.3. Order of Precedence | 25
8. Requirements | 26
8.1. System Definition 26
8.2. Characteristics | 27
8.2.1 Functional/Performance Requirements | 27
8.2.1.1. Connection to Website | 28
8.2.1.2. Determination Accuracy | 28
8.2.1.3. Thermal Sensor Node Area | 28
8.2.1.4. Video Latency | 28
8.2.1.5. Image Resolution | 28
8.2.2 Physical Characteristics | 29
8.2.2.1. Volume Envelope | 29
8.2.2.2. Mounting | 29
8.2.2.3. Installation 29
8.2.3 Electrical Characteristics | 29
8.2.3.1. Inputs | 29
8.2.3.1.1. Power Consumption | 29
8.2.3.1.2. Input Voltage Level | 29
8.2.3.2. Outputs | 30
8.2.3.2.1. Data Output | 30
8.2.3.2.2. Image Output | 30
8.2.3.3. Connectors | 30
8.2.4 Environmental Requirements | 30
8.2.4.1. Thermal Resistance | 30
8.2.4.1.1. Dielectrics Test | 30
8.2.5 Failure Propagation | 31
9. Support Requirements | 31

Functional System Requirements

List of Tables

Table 1: Responsibilities | 25
Table 2: Applicable Documents | 25
Table 3: Reference Documents | 26

Functional System Requirements

List of Figures

Figure 2: Conceptual Image | 24
Figure 3: Block Diagram of System | 27

Functional System Requirements

### 6. Introduction

### 6.1. Purpose and Scope

As industry demand grows, space inside medium voltage switchgear has become increasingly limited. Manufacturers are required to fit more devices and wires within the same limited space. Additionally, manufacturers are now being asked to include a remote viewing system within the switchgear to monitor a physical ground switch. This ground switch is physically blocked, by wires, from the view of the operator. Our project, Thermal Remote Viewing System within High Voltage, provides a real time visual depiction of the ground switch that an operator can view from a safe distance away from the switchgear. We will use a thermal sensor to create an image of the ground switch, which will then be sent to the microcontroller to process the information into a viewable format. The image information will then be sent to a web application for the operator to interface with. Our system will increase safety and efficiency for switchgear operators.

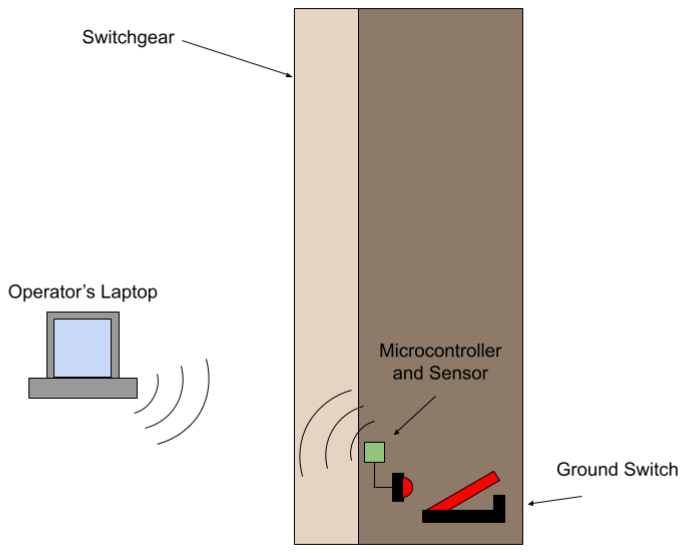
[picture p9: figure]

Figure 2: Conceptual Image

Functional System Requirements

### 6.2. Responsibility and Change Authority

Erica Mathew will make sure all requirements detailed in the Functional System Requirements will be met. Requirements can only be changed if Erica and our sponsors at Powell Industries approve of the changes. Below are the responsibilities of everyone in the team.

Subsystem | Responsibility
Thermal Image Sensor | Julia Garcia
Microcontroller | Blake Bagley
Web Application | Erica Mathew
Table 1: Responsibilities

### 7. Applicable and Reference Documents

### 7.1. Applicable Documents

The following documents, of the exact issue and revision shown, form a part of this specification to the extent specified herein:

Document Number | Revision/Release Date | Document Title
IEEE Standard C37.20.2 | 2015-09-22 | IEEE Standard for Metal-Clad Switchgear
IEEE Standard C37.04 | 2019-05-31 | IEEE Standard for Ratings and Requirement for AC High- Voltage Circuit Breakers with a Rated Maximum Voltage Above 1000V
IEEE Standard C37.09 | 2019-04-11 | IEEE Standard Test Procedures for AC High-Voltage Circuit Breakers with Rated Maximum Voltage Above 1000 V
ANSI C37.54 | 2023 | American National Standard for Alternating Current High-Voltage Circuit Breakers Applied in Metal-Enclosed Switchgear— Conformance Test Procedures
NFPA 70E | 2024 | Standard for Electrical Safety in the Workplace
NFPA 70 | 2023 | National Electrical Code
Table 2: Applicable Documents

Functional System Requirements

### 7.2. Reference Documents

The following documents are reference documents utilized in the development of this specification. These documents do not form a part of this specification and are not controlled by their reference herein.

Document Number | Revision/Release Date | Document Title
1 | Version 1.9 | ESP32-S3 Series Datasheet
2 | Revision 400 | FLIR LEPTON® Engineering Datasheet
3 | 12/22/2020 | GlobTek, Inc. Li-Ion Polymer 3.7V Battery Pack
4 | Version 2 | DS-16912-FLiR Lepton Breakout Board V2
5 | Revision 100 | Female_Headers.100_DS
Table 3: Reference Documents

### 7.3. Order of Precedence

In the event of a conflict between the text of this specification and an applicable document cited herein, the text of this specification takes precedence without any exceptions.
All specifications, standards, exhibits, drawings, or other documents that are invoked as “applicable” in this specification are incorporated as cited. All documents that are referred to within an applicable report are considered to be for guidance and information only, except ICDs that have their relevant documents considered to be incorporated as cited.

Functional System Requirements

### 8. Requirements

### 8.1. System Definition

The Thermal Remote Viewing System within High Voltage is a system specifically designed for remotely monitoring ground switches within a medium voltage switchgear. It allows operators to confirm a vertical tower is properly grounded before opening the switchgear. This system provides a real-time image stream of the grounding switch that will be broadcast to an online website. The system consists of a thermal image sensor, microcontroller, and a website.

Figure 3: Block Diagram of System
There are three main components to this system. The first block represents the first main component which is the thermal image sensor. This sensor will take in infrared values and turn them into an image for the microcontroller to process. This sensor will need to be configured to be in the image format that will be used by the microcontroller.
The second block, which is the microcontroller, will use an algorithm to determine where the switch is located and to determine if the grounding switch is open or closed. The image and switch state will be then sent from the microcontroller to the website to be viewed by the operator.

Functional System Requirements

### 8.2. Characteristics 8.2.1 Functional / Performance Requirements 8.2.1.1. Connection to Website

The Thermal Remote Viewing System shall allow for the microcontroller and thermal image sensor to be connected to the website.

Rationale: This will allow the operator to view multiple vertical towers.

### 8.2.1.2. Determination Accuracy

The Switch State Determination done by the microcontroller shall not have an error rate exceeding 10%.

Rationale: This will allow the machine learning of the microcontroller to perform as accurately as needed.

### 8.2.1.3. Thermal Sensor Node Area

The thermal sensors should take a visual image that covers a minimum viewable area of 6x6 inches.

Rationale: This is a requirement specified by our customer to properly see the gap between contacts in the ground switches.

### 8.2.1.4. Video Latency

The website should output images frame by frame to mimic a slow video stream.

Rationale: This is a requirement specified by our customer to properly view the gap between contacts in the ground switches.

### 8.2.1.5. Image Resolution

The image output shall have a pixel resolution of 160x120 pixels.

Rationale: This is the resolution of the thermal sensor chosen. This will allow for a clear image for the operator to observe.

Functional System Requirements

### 8.2.2 Physical Characteristics 8.2.2.1. Volume Envelope

The volume envelope of the Remote System shall be less than or equal to 6 inches in height, 6 inches in width, and 6 inches in length.

Rationale: This is a requirement specified by our customer due to constraints of the switchgear where the system will operate.

### 8.2.2.2. Mounting

The thermal sensor should be mounted facing the grounding switch to allow for a complete view. The mounting information shall be captured in the Remote Viewing System within High Voltage ICD.

Rationale: This is a requirement specified by our customer to provide a clear image for the operator.

### 8.2.2.3. Installation

The installation information for The Thermal Remote Viewing System within High Voltage shall be provided to the customer through a user manual.

### 8.2.3 Electrical Characteristics 8.2.3.1. Inputs

No inputs of the operator shall inhibit the function of The Thermal Remote Viewing System.

Rationale: By design, this should limit the risk of the system becoming damaged.

### 8.2.3.1.1. Power Consumption

The maximum peak power of the system shall not exceed 3 watts.
For our class demonstration we will use a battery pack to power our system. If this system were to be added into a switchgear, it shall pull power from the switchgear itself.

Rationale: This is specified by the ESP32-S3 Series Datasheet and FLIR LEPTON® Engineering Datasheet.

### 8.2.3.1.2. Input Voltage Level

The input voltage level for the Search and Rescue System shall be +3.7 VDC to +4.2 VDC.

Rationale: This is specified by GlobTek, Inc. Li-Ion Polymer 3.7 V Battery Pack Datasheet.

Functional System Requirements

### 8.2.3.2. Outputs 8.2.3.2.1. Data Output

The Thermal Remote Viewing System within High Voltage shall include a website interface compatible with the microcontroller to view the ground switch.

Rationale: The Thermal Remote Viewing System within High Voltage information passes directly to the customer’s system.

### 8.2.3.2.2. Image Output

The Thermal Remote Viewing System shall output an 8-bit grayscale image stream for the operator to view on the system’s website.

Rationale: This is a requirement specified in the FLIR LEPTON® Engineering Datasheet.

### 8.2.3.3. Connectors

The Thermal Remote Viewing System within High Voltage shall follow the America National Standard for Electrical Connectors ANSI C119.6-2011.

Rationale: This is a requirement specified in accordance with our battery.

### 8.2.4 Environmental Requirements

The Thermal Remote Viewing System shall be designed to withstand and operate in the environments and laboratory tests specified in the following section.

Rationale: This is a requirement specified by our customer due to constraints of the switchgear where the system will operate.

### 8.2.4.1. Thermal Resistance

The Thermal Remote Viewing System should be able to properly operate in an environmental temperature up to 80° C.

Rationale: This is a requirement specified in the FLIR LEPTON® Engineering Datasheet.

### 8.2.4.2. Dielectrics Test

The Thermal Remote Viewing System shall not compromise the integrity of the dielectrics already within the switchgear.

Rationale: This is a requirement specified by our customer due to constraints of the switchgear where the system will operate.

Functional System Requirements

### 8.2.5 Failure Propagation

If the website doesn’t receive image input, the website shall display a notice that the ‘Server is Down’.

Rationale: This will allow the user to know if something is wrong with the system.

### 9. Support Requirements

The Thermal Remote Viewing System shall require internet connection and a computer in order to interact with the website application.

## Remote Viewing Within High Voltage Apparatus

## Blake Bagley Julia Garcia Erica Mathew

# Interface Control Document

REVISION – 3
26 April 2025

Interface Control Document

### INTERFACE CONTROL DOCUMENT

### FOR

## Remote Viewing within High Voltage Apparatus

TEAM <54>

APPROVED BY:

__________________________________
Project Leader | Date

__________________________________
Prof. Kalafatis | Date

__________________________________
T/A | Date

Interface Control Document

Change Record

Rev. | Date | Originator | Approvals | Description
1 | 12/5/2024 | Erica Mathew | | Draft Release
2 | 4/2/2025 | Julia Garcia | | April Update
3 | 4/26/2025 | Julia Garcia | | Final Release

Interface Control Document

Table of Contents

Table of Contents 35
List of Tables | 36
List of Figures | 37
10.Overview | 38
11.References and Definitions | 38
11.1. References 38
11.2. Definitions 38

### 12. Physical Interface 38

12.1. Weight 38
12.1.1 Weight of Printed Circuit Board Version 1 38 12.1.2 Weight of Printed Circuit Board Version 2 38 12.1.3 Weight of Complete System 38
12.2. Dimensions 39
12.2.1 Dimensions of Printed Circuit Board Version 1 39 12.2.2 Dimensions of Printed Circuit Board Version 2 39 12.2.3 Dimensions of Complete System 39
12.3. Mounting Locations 39
13. Thermal Interface | 39
14.Electrical Interface | 40
14.1. Primary Input Power | 40
14.2. Voltage and Current Levels | 40
14.2.1 Maximum Values | 40
14.2.2 Nominal Values | 41
14.3. Data Interface | 41
14.4. User Control Interface | 41
15.Communications / Device Interface Protocols | 41
15.1. Wireless Communication | 41
15.1.1 Wi-Fi | 41

Interface Control Document

List of Tables
Table 4: Original Printed Circuit Board Weight | 38
Table 5: Updated Printed Circuit Board Weight | 38
Table 6: System Weight | 38
Table 7: Original Printed Circuit Board Dimensions | 39
Table 8: Updated Printed Circuit Board Dimensions | 39
Table 9: System Dimensions | 39
Table 10: Maximum Voltage, Current and Power Levels | 40
Table 11: Nominal Voltage, Current and Power Levels | 40

Interface Control Document

List of Figures
Figure 4: Electrical Interface Diagram | 40

Interface Control Document

### 10. Overview

This document is provided to detail how the thermal sensor will interface with the microcontroller and how the microcontroller will interface with the website. It will list all inputs, outputs, and how the system manages each. An explanation of the inputs from the thermal sensor to the microcontroller will be provided. Then, an explanation of how that input will be transferred from the microcontroller to the website will follow.

### 11. References and Definitions

### 11.1. References

Refer to section 2.2 of the Functional System Requirements document.

### 11.2. Definitions

mA | Milliamp
mW | Milliwatt
g | Grams
mm | Millimeters
V | Volts

### 12. Physical Interface

### 12.1. Weight

| 12.1.1 Weight of Printed Circuit Board Version 1
Component | Weight [g] | Number of Items | Total Weight [g]
PCB without battery | 18.391 | 1 | 18.391
PCB with battery | 34.015 | 1 | 34.015
Table 4: Original Printed Circuit Board Weight

### 12.1.2 Weight of Printed Circuit Board Version 2

Component | Weight [g] | Number of Items | Total Weight [g]
PCB without battery | 13.737 | 1 | 13.737
PCB with battery | 29.361 | 1 | 29.361
Table 5: Updated Printed Circuit Board Weight

### 12.1.3 Weight of Complete System

Component | Weight [g] | Number of Items | Total Weight [g]
PCB inside the case, without battery | 54.737 | 1 | 54.737
PCB inside the case, with battery | 70.361 | 1 | 70.361

Table 6: System Weight

Interface Control Document

### 12.2. Dimensions 12.2.1 Dimensions of Printed Circuit Board Version 1

Component | Length [mm] | Width [mm] | Height [mm]
Original PCB | 66.929 | 51.435 | 10
Table 7: Original Printed Circuit Board Dimensions

### 12.2.2 Dimensions of Printed Circuit Board Version 2

Component | Length [mm] | Width [mm] | Height [mm]
Updated PCB | 66.929 | 42.545 | 37.5
Table 8: Updated Printed Circuit Board Dimensions

### 12.2.3 Dimensions of Complete System

Component | Length [mm] | Width [mm] | Height [mm]
Updated PCB inside the case | 77.47 | 58.04 | 59.06
Table 9: System Dimensions

### 12.3. Mounting Locations

The thermal sensor will be mounted at least 6 inches away from and facing the grounding switch at the back of the switchgear. The sensor must face the grounding switch because the operator is viewing the switch. It can only fit in the back due to space constraints within the switchgear.

### 13. Thermal Interface

The case protecting the system is made of ABS which is rated to withstand temperatures up to 95 °C.
The case has a window made of IR material to increase the accuracy of the sensor.

Interface Control Document

### 14. Electrical Interface

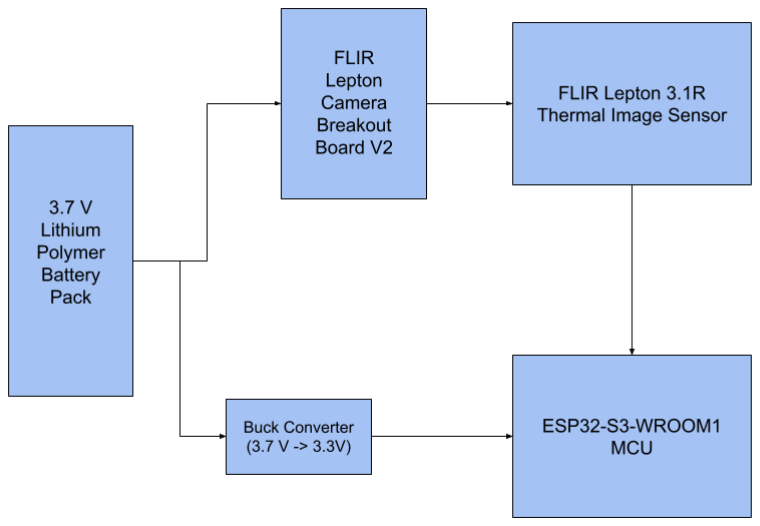
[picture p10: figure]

Figure 4: Electrical Interface Diagram

### 14.1. Primary Input Power

The system will be battery powered using a rechargeable 3.7 V lithium-ion polymer battery. When implemented into the switchgear, the system will be powered by the switchgear itself.

### 14.2. Voltage and Current Levels 14.2.1 Maximum Values

Component | Voltage [V] | Current [mA] | Power [mW]
FLIR Lepton 3.1R Thermal Sensor | 4.8 | 16 | 76.8
FLIR Lepton 3.1R Thermal Sensor Core | 1.5 | 110 | 165
FLIR Lepton 3.1R Thermal Sensor I/O | 4.8 | 310 | 1488
ESP32-S3-WROOM-1 | 3.6 | 1500 | 3600
Table 10: Maximum Voltage, Current, and Power Levels

Interface Control Document

### 14.2.2 Nominal Values

Component | Voltage [V] | Current [mA] | Power [mW]
FLIR Lepton 3.1R Thermal Sensor | 2.8 | 14 | 39.2
FLIR Lepton 3.1R Thermal Sensor Core | 1.2 | 84 | 100.8
FLIR Lepton 3.1R Thermal Sensor I/O | 3.1 | 235 | 728.5
ESP32-S3-WROOM-1 | 3.3 | 500 | 1650
Table 11: Nominal Voltage, Current, and Power Levels

### 14.3. Data Interface

The thermal sensor will send raw image data to the microcontroller through serial pins (SPI), the microcontroller is mounted to the PCB and the sensor is housed in the breakout board connected to the board.

### 14.4. User Control Interface

The user control interface is a website that communicates with the microcontroller. The user will login using credentials provided through their companies. Then, the user will be able to select what switchgear vertical tower will be viewed. The user can select the desired image stream from the overview page, or the user can use the search bar to find their desired image stream.

### 15. Communications / Device Interface Protocols

### 15.1. Wireless Communications 15.1.1 Wi-Fi

The microcontroller has a built-in Wi-Fi module using IEEE 802.11b/g/n standards. This connection will be used to stream live images to the operator’s website.

## Remote Viewing Within High Voltage Apparatus

## Blake Bagley Julia Garcia Erica Mathew

# Subsystem Reports

REVISION – 3
26 April 2025

Subsystem Reports
Remote Viewing within High Voltage Apparatus | Revision – 3

### SUBSYSTEM REPORTS

### FOR

## Remote Viewing within High Voltage Apparatus

TEAM 54

APPROVED BY:

__________________________________
Project Leader | Date

__________________________________
Prof. Kalafatis | Date

__________________________________
T/A | Date

Subsystem Reports
Remote Viewing within High Voltage Apparatus | Revision – 3
Change Record
Rev. | Date | Originator | Approvals | Description
1 | 12/5/2024 | Erica Mathew | | Draft Release
2 | 4/2/2025 | Julia Garcia | | April Update
3 | 4/26/2025 | Julia Garcia | | Final Release

Subsystem Reports
Remote Viewing within High Voltage Apparatus | Revision – 3
Table of Contents
Table of Contents 45
List of Figures | 46
16. Introduction | 47
17. Thermal Sensor/PCB Subsystem Report | 47
17.1. Subsystem Introduction | 47
17.2. Subsystem Details | 48
17.3. Subsystem Validation | 50
17.4. Subsystem Conclusion | 51
18. Microcontroller Subsystem Report | 52
18.1. Subsystem Introduction | 52
18.2. Subsystem Details | 52
18.3. Subsystem Validation | 55
18.4. Subsystem Conclusion | 60
19. Web Interface Subsystem Report | 61
19.1. Subsystem Introduction | 61
19.2. Subsystem Details | 61
19.2.1 Login/Registration Page | 61
19.2.2 Overview Page | 63
19.2.3 Map Builder Page | 63
19.2.3.1. Drag and Drop | 64
19.2.3.2. Saving and Loading | 64
19.2.3.3. Resetting Map | 64
19.2.3.4. Navigating to Video Page 64 19.2.4 Video Page 65
19.2.4.1. Server Side | 65
19.2.4.2. Video Page Front End | 66
19.3. Subsystem Validation | 66
19.3.1 Receiving Video | 66
19.3.2 Login System | 66
19.3.3 Search Bar | 67
19.3.4 Video Display Page 67
19.4. Subsystem Conclusion | 67

Subsystem Reports
Remote Viewing within High Voltage Apparatus | Revision – 3
List of Figures
Figure 5: Subsystem Breakdown | 47
Figure 6: Functional Block Diagram of the Thermal Sensor/PCB Subsystem | 48
Figure 7: Buck Converter Schematic for ESP32 Input | 48
Figure 8: ESP32-S3-WROOM-1 Connections | 49
Figure 9: PCB Layout | 49
Figure 10: ABS Plastic Case | 49
Figure 11: Results of ESP32 Buck Converter Shown by Multimeter | 50
Figure 12: ESP32 Buck Converter Output Voltage on Oscilloscope | 50
Figure 13: Data Stream Between the Sensor and Microcontroller on Oscilloscope | 51
Figure 14: Completed System Hardware | 51
Figure 15: Camera Communication Flowchart | 53
Figure 16: Normalization Equation | 53
Figure 17: Image Processing Flowchart | 54
Figure 18: Wi-Fi Connection (Laptop View) | 55
Figure 19: Wi-Fi Connection (PuTTY View) | 55
Figure 20: Segment ID Test | 56
Figure 21: Room Temperature Test | 57
Figure 22: Hand Temperature Test | 57
Figure 23: MATLAB Photo Test | 57
Figure 24: Makeshift Box for Testing | 58
Figure 25: Switch State Test (Closed) | 59
Figure 26: Switch State Test (Open) | 59
Figure 27: Website Communication Test (ESP_IDF) | 60
Figure 28: Website Communication Test (Website) | 60
Figure 29: Subsystem Block Diagram | 61
Figure 30: Login Page | 62
Figure 31: Registration Page | 62
Figure 32: Firebase Authentication | 62
Figure 33: Overview Page | 63
Figure 34: Map Builder Page | 63
Figure 35: Image Received by Website | 65
Figure 36: Raw Data to PNG | 65
Figure 37: Video Page | 66
Figure 38: Website Overview | 67

Subsystem Reports
Remote Viewing within High Voltage Apparatus | Revision – 3

### 16. Introduction

The first subsystem is the thermal sensor and PCB, the power supply is housed on the board along with the microcontroller. The thermal sensor is housed on the breakout board attached to the main PCB. All components are housed in an ABS plastic encasing. Below is the subsystem breakdown for our Thermal Remote Viewing System.

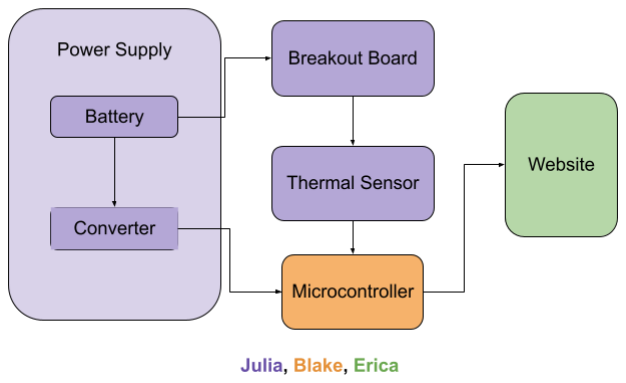
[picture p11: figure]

Figure 5: Subsystem Breakdown

### 17. Thermal Sensor/PCB Subsystem Report (Julia Garcia)

### 17.1. Subsystem Introduction

The thermal sensor/PCB is the subsystem that contains all the hardware of the system. This includes the power supply, the microcontroller, the camera module, and the ABS plastic encasing. For the power supply, a lithium-ion battery pack is connected to a buck converter to power the microcontroller and to the breakout board for the camera module. The microcontroller will be connected to the camera module through serial communication (SPI). The purpose of this subsystem is to provide power to both major components, ensure data transfer between them, and protect the system and the switchgear.
The breakout board replaced three buck converters that provided power to the camera module directly. The camera socket wasn’t able to be hand soldered while maintaining the functionality of the part. The breakout board adds height and weight to the overall system, but it reduces the size of the main board, and the number of parts needed. The breakout board attaches to the board with a connector and is removable, though this isn’t relevant to the operator because they don’t interact with the hardware.
The ABS plastic encasing protects the sensor from the high voltage of the switchgear and ensures the dielectric integrity within the switchgear is maintained.

Subsystem Reports
Remote Viewing within High Voltage Apparatus | Revision – 3

### 17.2. Subsystem Details

A block diagram of the subsystems is shown below.

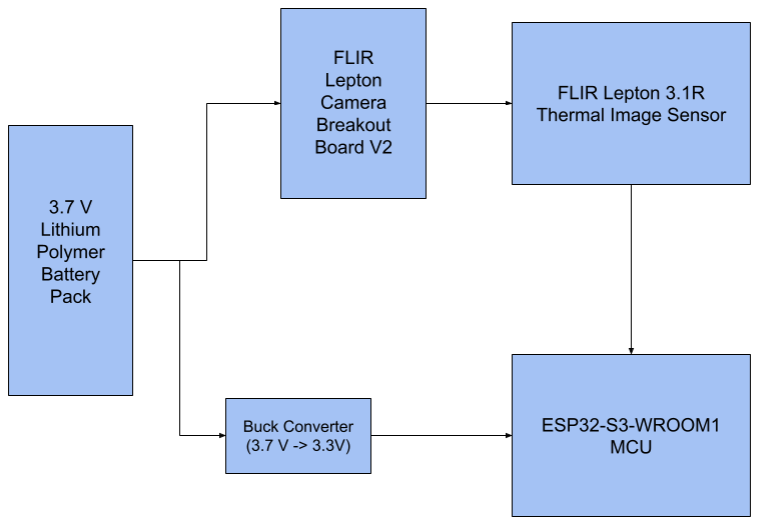
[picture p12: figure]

Figure 6: Functional Block Diagram of the Thermal Sensor/PCB Subsystem
The camera module needs three separate power inputs to operate. The core of the camera (VDDC), the sensor itself (VDD), and the input/output ring (VDDIO) all need to be powered separately. This is done by the breakout board that houses the camera socket. The microcontroller needs pull-down resistors and push-buttons to function and be programmed, while also needing to be powered. The SPI interface between the microcontroller and the camera module requires four pins on each device to be allocated in order for the data to transfer properly.
The layout of the buck converter is shown in the figure below.

Figure 7: Buck Converter Schematic for ESP32 Input

Subsystem Reports
Remote Viewing within High Voltage Apparatus | Revision – 3
The connections for the microcontroller are shown in the figure below.

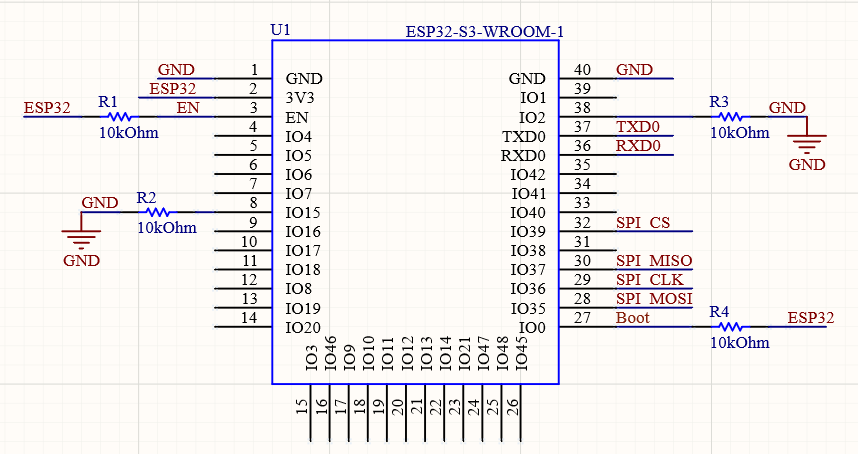
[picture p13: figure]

Figure 8: ESP-S3-WROOM-1 Connections
The overall layout of PCB is shown in the figure below.

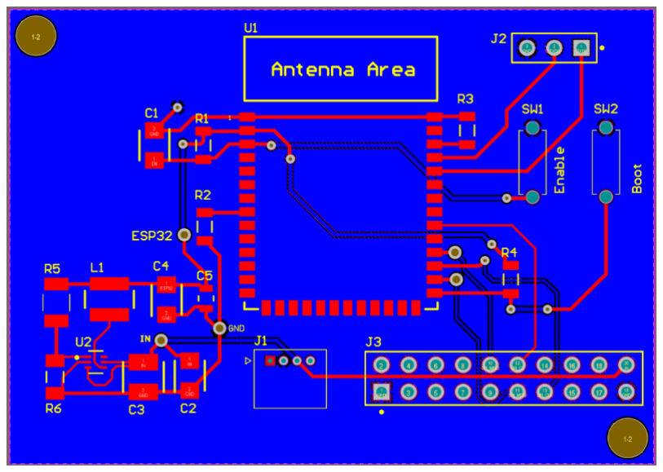
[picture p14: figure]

Figure 9: PCB Layout
The ABS plastic encasing is shown in the figure below.

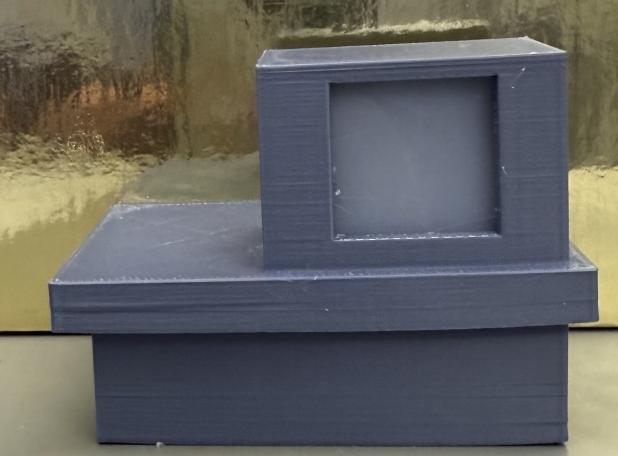
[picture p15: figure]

Figure 10: ABS Plastic Case

Subsystem Reports
Remote Viewing within High Voltage Apparatus | Revision – 3

### 17.3. Subsystem Validation

To validate the functionality of the PCB, the buck converter was tested with a multimeter to ensure the output value was within acceptable limits. The values on the data sheets of the components were nominal values, therefore slightly higher or lower would still power the components. The output was also tested with an oscilloscope to see if the DC voltage had an acceptable ripple.
The three figures below show the results of the buck converter, the input for the microcontroller, and the data stream between the sensor and microcontroller.

Figure 11: Results of ESP32 Buck Converter Shown by Multimeter

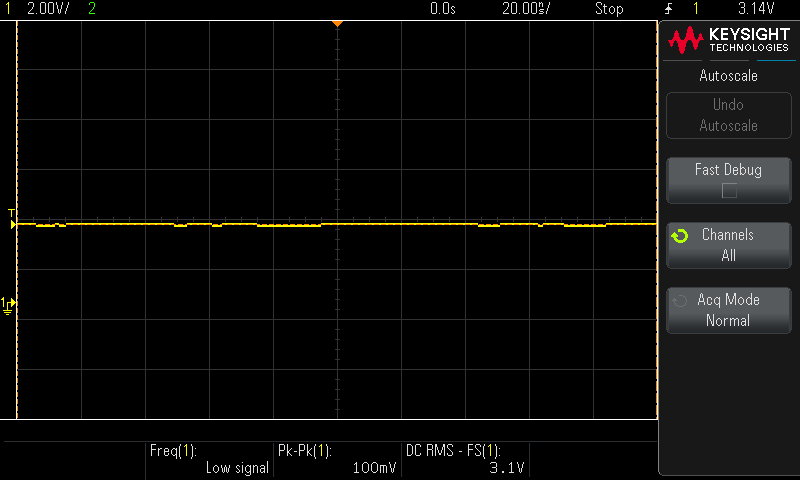
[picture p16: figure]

Figure 12 : ESP32 Buck Converter Output Voltage on Oscilloscope

Subsystem Reports
Remote Viewing within High Voltage Apparatus | Revision – 3

Figure 13: Data Stream Between the Sensor and Microcontroller on Oscilloscope

### 17.4. Subsystem Conclusion

The goal of this subsystem is to ensure the two major components can receive power and communicate with each other. The hardware of the system is what provides the images for the microcontroller to send and for the website to receive.
This subsystem was changed from one board with four buck converters, the microcontroller and the thermal sensor all mounted on it to a board with one buck converter, the microcontroller, and a connector with a breakout board, which houses the thermal sensor, attached. All four buck converters were functional, and the microcontroller was able to download code, but the camera socket wasn’t able to be hand soldered without losing functionality. This caused the change of the socket to be mounted directly to the board to the breakout board being separated and attached through a connector.
The subsystem is completely functional, the correct voltage level is provided to the breakout board and the microcontroller. The microcontroller is able to download and run the code provided by subsystem two (microcontroller). The thermal sensor and microcontroller communicate successfully which allows image data to be displayed by subsystem three (website).
The figure below shows the completed subsystem.

Figure 14: Completed System Hardware

Subsystem Reports
Remote Viewing within High Voltage Apparatus | Revision – 3

### 18. Microcontroller Subsystem Report (Blake Bagley)

### 18.1. Subsystem Introduction

This subsystem is made up of the microcontroller and the code that will be uploaded to it. As stated previously in this report, the microcontroller has three main jobs: Take the image data from the thermal image sensor and process the image to determine if the switch is open or closed and send both the image data and the determination to the website.

### 18.2. Subsystem Details

The microcontroller will first attempt to connect to the operator’s laptop. It does this by declaring itself as a station and sets a connection to the laptop’s hotspot. This hotspot will give the microcontroller the ability to access the website.
The next thing the microcontroller does is capture the image data from the thermal camera. To describe how the microcontroller takes in the data from the thermal imager, we first need to understand how the thermal imager is sending data. The Lepton 3.1R uses SPI communication to send its data. It does this by separating rows of pixel data into packets. Each packet consists of 80 pixels of data. Those packets are then separated into four different segments each containing 60 packets. Through SPI communication, the thermal imager will send one packet per falling edge of the chip select signal. Also, for each segment, the twentieth packet will have the ID of the segment that is currently being read. With all of this in mind, the following is how the microcontroller takes in the image data. First, the code will continuously read for valid packets until it reads a packet with an ID of zero. Then, it will start to store the packets into memory until the twentieth packet is read. If the segment number is invalid, the memory will be reset and the reading process from before will start again. If not, the segment will finish being read, and the code will restart the process of looking for the next segments until all segments are read and stored. Below is a flowchart to further describe the code snippet.

Subsystem Reports
Remote Viewing within High Voltage Apparatus | Revision – 3

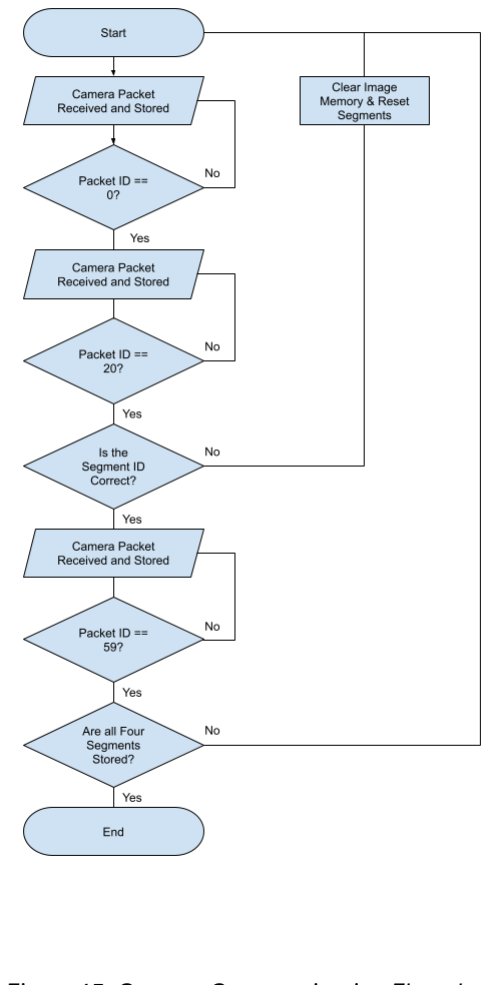
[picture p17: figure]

Figure 15: Camera Communication Flowchart
Next, the code will compress the image and process it to determine if the switch that the camera is fixed on is open or closed. It will do this by reading temperature differences between the entire frame and a smaller area of the frame in which the contact of the switch is located when the switch is closed. Firstly, the image data stored isn’t normalized at all, so it would be fairly difficult to do math that could read temperature differences. So, the code normalizes the pixel data to range from 0 to 255 using the equation below.
Tn = (ti − tmin) (

255

tmax − tmin

)

Figure 16: Normalization Equation

Tn = normalized temperatures ti = current temperature
tmax = maximum temperature tmin = minimum temperature

Subsystem Reports
Remote Viewing within High Voltage Apparatus | Revision – 3
This will also make the image data quicker to send to the website as well as provide a clearer image. Then the code will calculate the average temperatures of both areas and determine the switch’s state on whether the difference in the temperatures is high enough or not. If there is a significant difference, the microcontroller will determine that the switch is closed. The flowchart below further describes the code’s process.

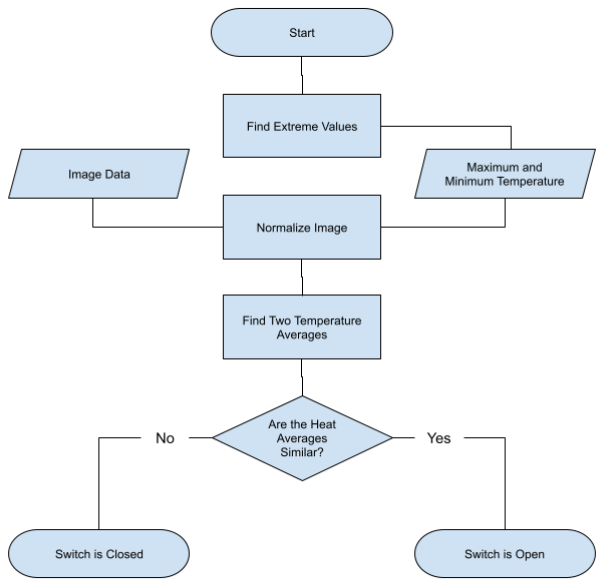
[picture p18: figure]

Figure 17: Image Processing Flowchart

Finally, the code will send the image data and the determination to the website. This is done by using HTTP post requests. The microcontroller will create a post request that has the image, and the determination stored in separate headers. In other words, it will configure an HTTP Client to connect to the website, set the post request, and then send it to the website. The code will then loop back to trying to read an image from the camera and keep looping.

Subsystem Reports
Remote Viewing within High Voltage Apparatus | Revision – 3

### 18.3. Subsystem Validation

To validate the Wi-Fi connection of the microcontroller, a laptop was used as a device for the microcontroller to connect to. It was specifically set for the microcontroller to connect to the laptop’s hotspot. The snapshots from the laptop and the ESP-IDF console below show that the Wi-Fi connection is made.

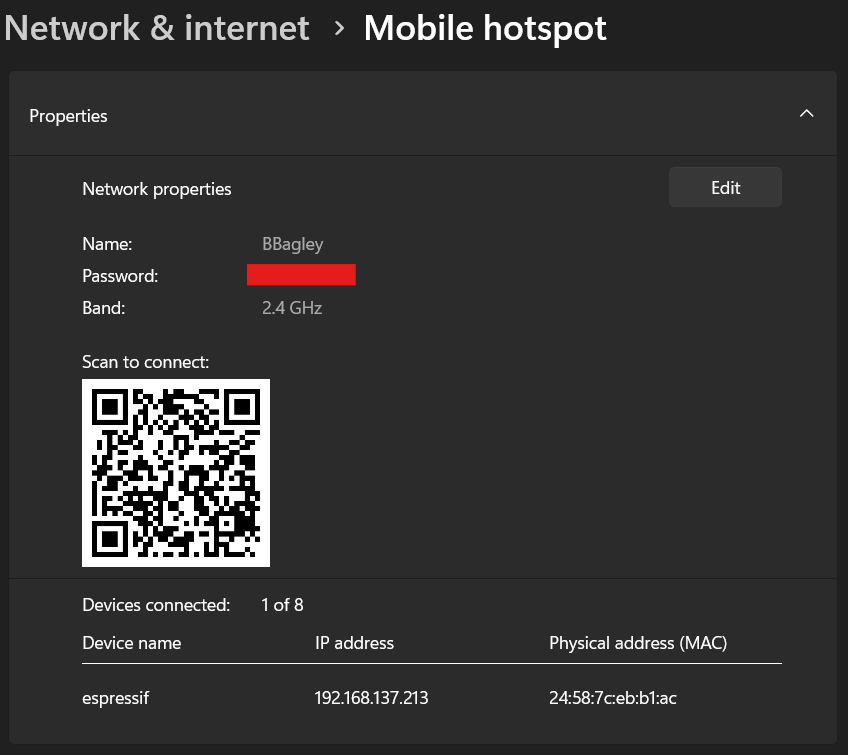
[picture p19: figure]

Figure 18: Wi-Fi Connection (Laptop View)

Figure 19: Wi-Fi Connection (PuTTY View)

Subsystem Reports
Remote Viewing within High Voltage Apparatus | Revision – 3
To validate the communication between the camera and the microcontroller, three tests were performed. The first test was to see if the pixel data was being stored in the correct order. This was done by having the code print the segment ID at the twentieth packet of each segment and then checking stored values to see if they aligned. The snapshot below shows that the code read through invalid segments until it finally got to the correct ones and stored them. The first number on the left represents the segment ID and the second number represents the packet ID. The segment ID should read in order as 1, 2, 3, and 4. However, when the data is read in, the numbers for the segment ID are shifted by 4 bits. Therefore, in the screenshot, they should read as 16, 32, 48, and 64. It also does a check to see if the packets were stored correctly by printing the ID of the twentieth packet of the stored data. The ID should be 16 if the data is stored correctly.

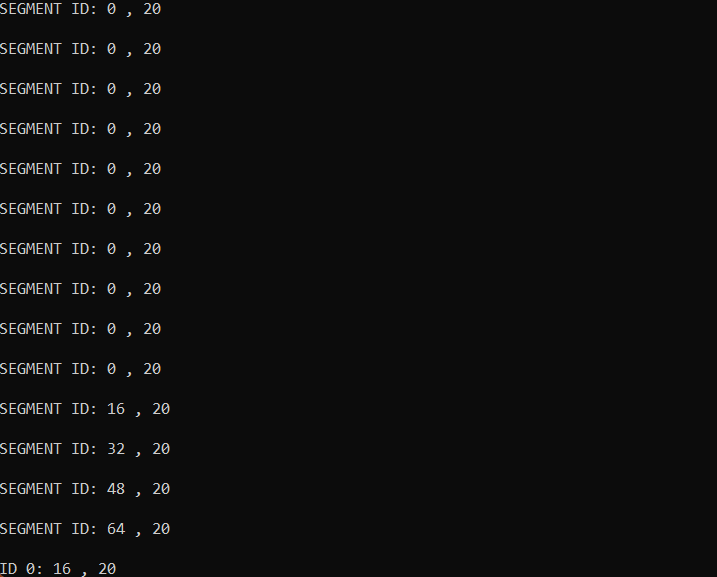
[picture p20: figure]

Figure 20: Segment ID Test
The second test checks if the code will ignore invalid frames. In the previous figure, it shows that the segments whose ID is 0 get skipped until a valid ID of 16, 32, 48, or 64 is read.
The next test is to check temperature reading to make sure they align with the temperature in front of the camera. This was done by putting two different heat readings in front of it. One of the temperature readings had nothing in front of the camera. The other had a hand fully covering the view of the camera.
There are two screenshots below. The first showing the first 10-pixel values of the camera when nothing is in frame and the second showing pixel values of the camera when a hand is in frame. The screenshots show that a higher pixel intensity is read when a hand is in front of the camera. Therefore, the microcontroller is correctly reading temperature increases and decreases from the camera.

Subsystem Reports
Remote Viewing within High Voltage Apparatus | Revision – 3

Figure 21: Room Temperature Test

Figure 22: Hand Temperature Test
Finally, it was tested by pulling the image data from the microcontroller and displaying it in MATLAB. The image below is of a desk showing that the microcontroller is receiving image data correctly.

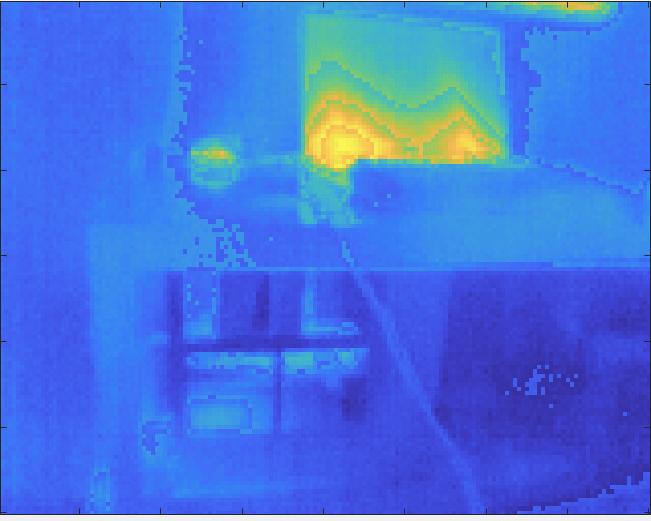
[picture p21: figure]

Figure 23: MATLAB Photo Test

Subsystem Reports
Remote Viewing within High Voltage Apparatus | Revision – 3
To validate the image processing, the code needed to be checked to ensure it was reading the temperature differences in the correct regions. The region of check should be located around the top left corner of the camera's sight. To test this, a makeshift switch was created, using a cardboard box that has two holes to mimic the positions of the real switch. One of the holes was located in the window of check and the other is located in the opposite corner. Below is a photo of the box.

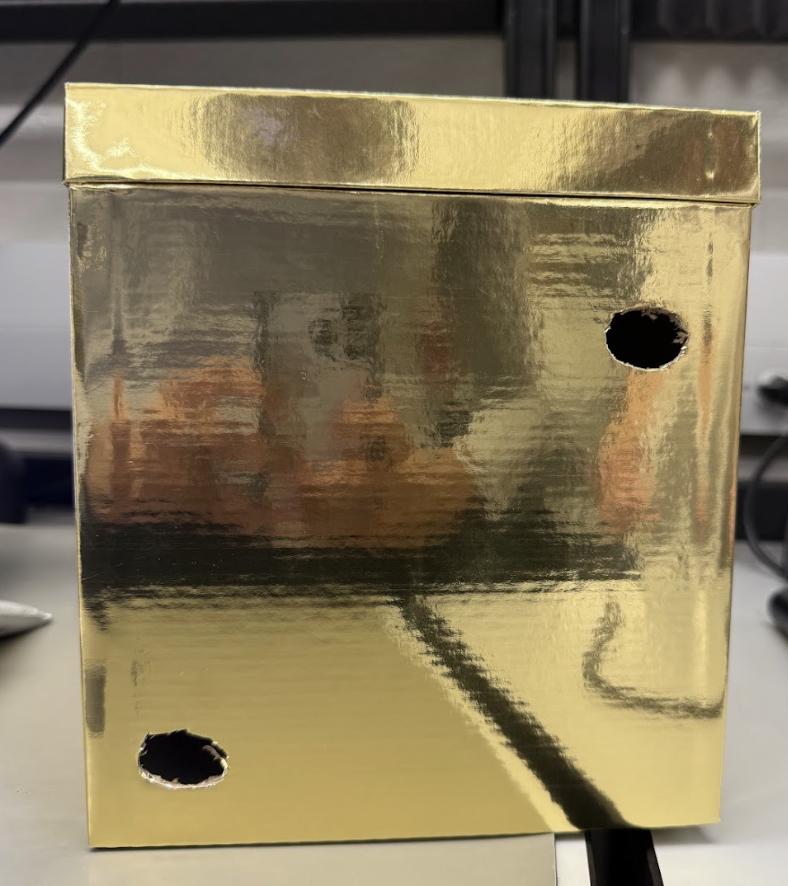
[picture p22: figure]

Figure 24: Makeshift Box for Testing

Subsystem Reports
Remote Viewing within High Voltage Apparatus | Revision – 3
While the system is running, if heat is read in the top hole, the microcontroller should output “Closed”, otherwise it should output “Open”. The two screenshots were taken from the website showing that the microcontroller is making the correct determinations.

Figure 25: Switch State Test (Closed)

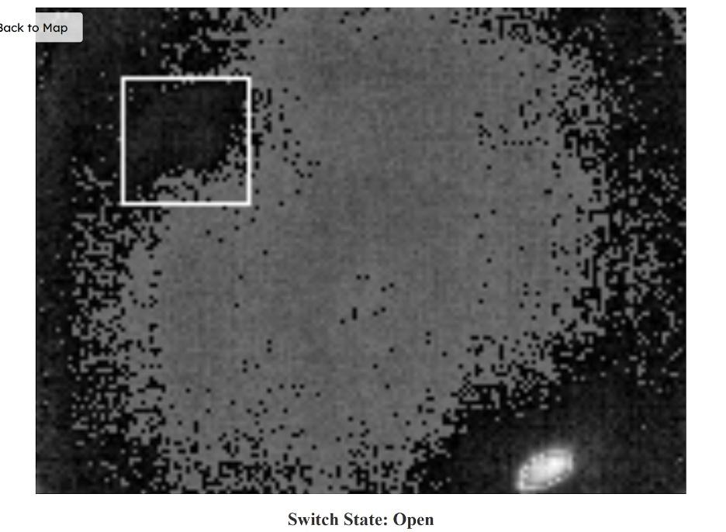
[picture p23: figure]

Figure 26: Switch State Test (Open)

Subsystem Reports
Remote Viewing within High Voltage Apparatus | Revision – 3
To validate that the microcontroller can send data to the website, we will send both image data and switch state data to the website and look for a message sent back to the microcontroller saying the information was sent correctly. The screenshot below shows that the microcontroller is sending data correctly because the website sent a message back saying “Image received and converted successfully” and tells the microcontroller the switch state that the website received. Below is also a screenshot from the website showing the image that was sent to the website properly.

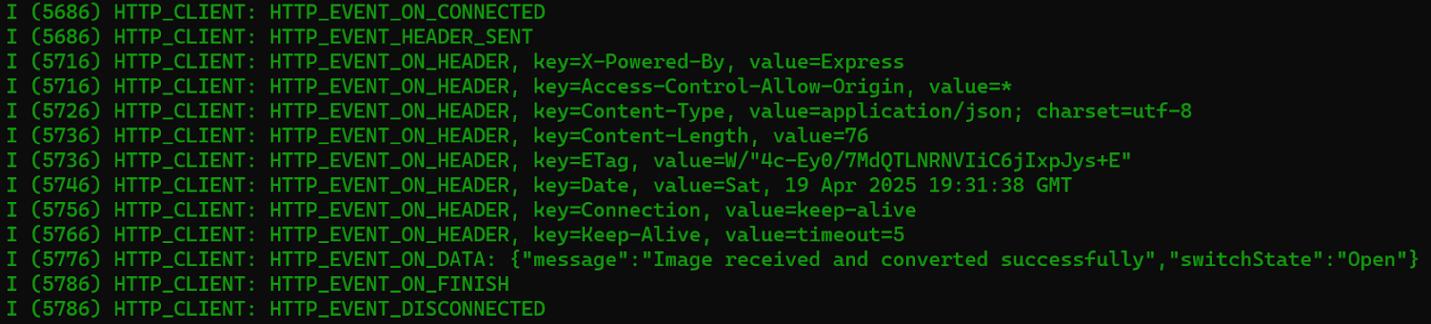
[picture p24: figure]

Figure 27: Website Communication Test (ESP_IDF)

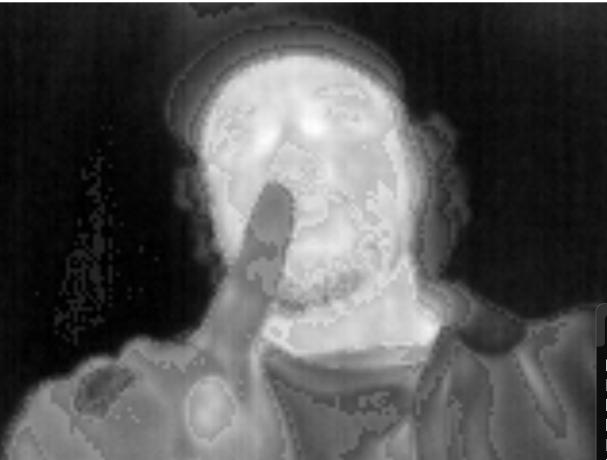
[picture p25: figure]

Figure 28: Website Communication Test (Website)

### 18.4. Subsystem Conclusion

The subsystem works as expected by the testing that has been done in the section above. It shows that the microcontroller is able to make a connection with the website, correctly read and store the data coming from the camera, process that data to determine the state of a switch, and send that information to the website.

Subsystem Reports
Remote Viewing within High Voltage Apparatus | Revision – 3

### 19. Web Interface Subsystem Report (Erica Mathew)

### 19.1. Subsystem Introduction

The web interface subsystem is designed to display a live image stream from a thermal sensor, allowing operators to monitor their switchgear setup more efficiently. The website includes a login/registration page, overview page, map builder page and video page. Below is a flowchart breaking down the website.


Figure 29: Subsystem Block Diagram

### 19.2. Subsystem Details 19.2.1 Login/Registration Page

The website opens to the Login Page, prompting users to enter their username and password. If they don’t have a profile there is a link directing the user to a registration page. On the registration page the user must enter their email address, password, and confirmation of their password. The website then checks if the imputed password and password confirmation matches. There are also checks written to validate that the password created is longer than 7 characters and the user provided a valid email address. If all validations pass, an account is created using Firebase Authentication. Firebase stores the user credentials in its local database. After successfully creating a profile, the user is redirected to the overview page.

Subsystem Reports
Remote Viewing within High Voltage Apparatus | Revision – 3

Figure 30: Login Page

Figure 31: Registration Page


Figure 32: Firebase Authentication
If the user already has a profile they can sign in on the Login page with their email address and password. When the form is submitted, Firebase works to authenticate the user by checking the provided credentials against its database. If authentication fails, an error message is displayed. If authentication is successful, the user is redirected to the overview page.

Subsystem Reports
Remote Viewing within High Voltage Apparatus | Revision – 3

### 19.2.2 Overview Page

The Overview page acts as a central hub of the website, allowing users to browse models, search for specific model IDs and navigate to the map builder page. At the top of the page there is a search bar to allow users to type a specific MODEL ID into the field and then press the magnifier icon to search. The search icon consists of a magnifier icon over an invisible search button; this was done to create a sleek appearance throughout the website. The search bar’s event listener handles ‘click’ events from the search button. Then the user’s input is trimmed and converted to uppercase. If the user’s input matches an available model, the user is redirected to the MODEL ID’s video page. If the input does not match, an error message is displayed. The overview page also includes a video grid that allows users to click on blocks that represent MODEL IDs. Clicking a MODEL ID block will direct the user to that specific image stream. At the bottom of the page is a link called ‘Build Your Map’ that will redirect users to the map builder page.


Figure 33: Overview Page

### 19.2.3 Map Builder Page


Figure 34: Map Builder Page
This feature was created to allow operators to mimic their physical switchgear setup by dragging and dropping blocks that represent MODEL IDs. By clicking on a block, it will direct the user to its specific image stream.

Subsystem Reports
Remote Viewing within High Voltage Apparatus | Revision – 3

### 19.2.3.1. Drag and Drop

The drag and drop feature uses the interact.js library to enable smooth dragging. When a block is dragged the position is set to absolute (which allows the block to move freely), additionally the Z-index is changed to a high number that ensures it appears on top of any other element. When the block is dragged from the model-list (the available model IDs at the top) into the map area (the white box), the block's position is calculated relative to the new container. Once the block stops being dragged, the new position is calculated by finding the difference in the x coordinates (new position - old position) and the difference in the y coordinates to get a new (x, y) coordinate. The distance from the original position to the new position is calculated using the Pythagorean theorem and only if the distance is greater than 5 pixels is the movement registered. This is done to prevent unintentional movements and make the blocks move smoother.

### 19.2.3.2. Saving and Loading

Whenever a block located in the map-area is moved, its new location is saved to the browser's local storage. When the page is reloaded, there is a check to see if there is a saved layout; if there is then all blocks are moved to the saved position in the map area.

### 19.2.3.3. Resetting Map

On the map builder page there is a ‘Reset’ button that allows the user to clear the map area. Upon clicking the button, the user is asked for confirmation to clear the page. If confirmation is granted, the saved layout saved within local storage is removed. Additionally, all blocks in the map area are moved back into the model list and their position data is cleared.

### 19.2.3.4. Navigating to Video Page

The blocks have an event listener that detects clicks on a block. There is also a ‘dragging’ Boolean that is only set to ‘True’ when the block has been moved more than 5 pixels. When the event listener detects a click and the ‘dragging’ Boolean is set to false, the click is processed, and the user is redirected to that block's respective video page. This is done to prevent bugs while dragging blocks.

Subsystem Reports
Remote Viewing within High Voltage Apparatus | Revision – 3

### 19.2.4 Video Page

The Video Page displays images sent from the microcontroller one by one to mimic a slow video stream.

### 19.2.4.1. Server

The server receives both raw 8-bit grayscale data and a binary switch state from the microcontroller. The microcontroller sends an HTTP POST with a body (containing the raw image data) and a header with the Switch-State being either open or closed. The server listens for these POSTs at /ping; the incoming image requests are parsed into a buffer, while the switch-state headers update with the latest switch position. Below is an image of the server console shows that the image data was successfully received from the microcontroller.

Figure 35: Image Received by Website
Then, using the sharp library, the buffer is interpreted as a single-channel grayscale image and converted to a PNG. The picture is then saved on disk. Every time a new image data comes; the new image replaces the old image. Below is an example of what the 8-bit grayscale data looked like and what the Output PNG looked like after it has been converted.

Figure 36: Raw Data to PNG
Simultaneously, the server caches the new switch state as an in-memory variable. This gives two endpoints: POST /ping for image updates and GET /switch state for the most recent state.

Subsystem Reports
Remote Viewing within High Voltage Apparatus | Revision – 3

### 19.2.4.2. Video Page Front End

The front end of the video page has a big box at the center of the page displaying the image stream with the switch state written below it; the page also has two buttons at the top to navigate to the map and overview pages.


Figure 37: Video Page
This page has two elements: the <img> element for the image and the <span> element for the switch state. A timer is set to update both elements every 1.5 seconds. This forces the browser to fetch the newly saved PNG and the new switch state as either “Open”, “Closed” or “Unknown”. This allows the user to always see the most recent frame and switch state. As the image frames constantly update, a slow video stream is seen.

### 19.3. Subsystem Validation 19.3.1 Receiving Video

The website was validated to ensure the image stream was playing on the video page. This was confirmed by starting up the server and thermal camera and having the user navigate to the video page playing a live image stream.

### 19.3.2 Login System

The Login system was validated to ensure the login page would work with correct credentials and fail with incorrect credentials. This was confirmed by having the user register a new profile, confirm it can be found in Firebase, then log in with the new profile.

Subsystem Reports
Remote Viewing within High Voltage Apparatus | Revision – 3

### 19.3.3 Search Bar

The search bar was validated to ensure it would redirect users to the proper image stream. This was tested by having a user type an available MODEL ID and then confirm that they were directed to the correct video page. Additionally, the user typed an incorrect MODEL ID and was given an error message.

### 19.3.4 Video Display Page

The video display page (overview page) was validated by clicking different MODEL ID blocks and ensuring that the user was directed to the correct image stream.

### 19.4. Subsystem Conclusion

The goal of the website is to create a simple solution that allows switchgear operators to remotely monitor the state of a physical ground switch within their switchgear. This website allows for simplified monitoring of multiple image streams. The website displayed image frames (along with their accompanied switch states) at a constant rate to mimic a slow video stream.


Figure 38: Website Overview

## Remote Viewing Within High Voltage Apparatus

## Blake Bagley Julia Garcia Erica Mathew

# System Report

REVISION – 2
26 April 2025

System Report

### SYSTEM REPORT

### FOR

## Remote Viewing within High Voltage Apparatus

TEAM 54

APPROVED BY:

__________________________________
Project Leader | Date

__________________________________
Prof. Kalafatis | Date

__________________________________
T/A | Date

System Report

Change Record

Rev. | Date | Originator | Approvals | Description
1 | 4/2/2025 | Julia Garcia | | April Update
2 | 4/26/2025 | Julia Garcia | | Final Release

System Report

Table of Contents
Table of Contents | 71
List of Figures | 72
20. Overview | 73

### 21. Development Plan and Execution 73

21.1. Design | 73
21.2. Execution | 74
21.3. Validation | 75

### 22. Conclusion 76

22.1. Sponsor Feedback 76

System Report

List of Figures
Figure 39: 403 Execution Timeline | 74
Figure 40: 404 Execution Timeline | 74

System Report
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

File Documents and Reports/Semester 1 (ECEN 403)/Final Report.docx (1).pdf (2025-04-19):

# Remote Viewing within a High Voltage Apparatus

# Blake Bagley, Julia Garcia, Erica Mathew

## CONCEPT OF OPERATIONS

### REVISION – Draft 14 September 2024

CONCEPT OF OPERATIONS

FOR

## Remote Viewing within High Voltage Apparatus

TEAM <54>

APPROVED BY:

Project Leader | Date
Prof. Kalafatis | Date
T/A | Date

### Change Record

Rev . | Date | Originator | Approvals | Description
- | 9/14/2024 | Remote Viewing within High Voltage Apparatus | | Draft Release
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

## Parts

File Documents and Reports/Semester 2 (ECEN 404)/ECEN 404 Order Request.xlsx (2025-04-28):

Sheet: 403
Order Date | Part Number | Item Name | Location to Buy From | Cost per Part | Quantity | Total Cost | Item Description
2024-09-23 | 500-0771-01-ND | High Resolution LWIR Micro Thermal Camera Module Lepton 3.5 | https://www.digikey.com/en/products/detail/flir-lepton/500-0771-01/7606616 | $164.00 | 1 | $164.00 | Thermal Image Sensor 160HX120V
2024-09-23 | WM1721-ND | 1.25mm Pitch Wire To Wire Connector | https://www.digikey.com/en/products/detail/molex/0510210300/242843?gad_source=1 | $0.21 | 2 | $0.42 | 3 Rectangular Connectors - Housings Receptacle Natural 0.049" (1.25mm)
2024-09-23 | WM1744-ND | PICOBLADE 1.25 | https://www.digikey.com/en/products/detail/molex/0530480410/242866?gad_source=1 | $0.43 | 2 | $0.86 | Connector Header Through Hole, Right Angle 4 position 0.049" (1.25mm)
2024-09-23 | 1939-BL0750F5030481S1PCTC-ND | GlobTek Inc. Battery Pack Lithium Polymer 3.7 V | https://www.digikey.com/en/products/detail/globtek-inc/BL0750F5030481S1PCTC/16515787 | $6.47 | 1 | $6.47 | 3.7 V Lithium Polymer Battery Pack
 |  |  |  |  | Order Total | $171.75
 |  |  |  |  | Spent to date | $171.75
2024-10-14 | 296-50407-1-ND | IC REG BUCK ADJ 1A SOT5X3 | https://www.digikey.com/en/products/detail/texas-instruments/TLV62568ADRLR/9343350?_gl=1*p9x34z*_up*MQ.. | $0.22 | 8 | $1.76 | Buck Switching Regulator IC Positive Adjustable 0.6V 1 Output 1A
 |  |  |  |  | Order Total | $1.76
 |  |  |  |  | Spent to Date | $173.51
2024-10-15 | 581-KAM32LR72A475KU | Multilayer Ceramic Capacitor 4.7 uF | https://www.mouser.com/ProductDetail/581-KAM32LR72A475KU | $0.78 | 8 | $6.24 | Multilayer Ceramic Capacitors MLCC - SMD/SMT 100V 4.7uF X7R 1210
2024-10-15 | P105KAACT-ND | RES SMD 105K OHM 1% 1/2W 1210 | https://www.digikey.com/en/products/detail/panasonic-electronic-components/ERJ-14NF1053U/383828 | $0.33 | 4 | $1.32 | 105 kOhms ±1% 0.5W, 1/2W Chip Resistor 1210 (3225 Metric)
2024-10-15 | P383KACCT-ND | RES SMD 383K OHM 1% 3/4W 2010 | https://www.digikey.com/en/products/detail/panasonic-electronic-components/ERJ-12SF3833U/384404 | $0.46 | 4 | $1.84 | 383 kOhms ±1% 0.75W, 3/4W Chip Resistor 2010 (5025 Metric)
2024-10-15 | P412KAACT-ND | RES SMD 412K OHM 1% 1/2W 1210 | https://www.digikey.com/en/products/detail/panasonic-electronic-components/ERJ-14NF4123U/384090 | $0.33 | 4 | $1.32 | 412 kOhms ±1% 0.5W, 1/2W Chip Resistor 1210 (3225 Metric) Automotive AEC-Q200 Thick Film
 |  |  |  |  | Order Total | $10.72
 |  |  |  |  | Spent to Date | $184.23
2024-10-24 | ESP32-S3-WROOM-1-N16 | RF TXRX MOD BT WIFI PCB TH SMD | https://www.digikey.com/en/products/detail/espressif-systems/ESP32-S3-WROOM-1-N16/16162647 | $3.48 | 1 | $3.48 | Bluetooth, WiFi 802.11b/g/n, Bluetooth v5.0 Transceiver Module 2.4GHz PCB Trace Surface Mount
2024-10-24 | PREC003SAAN-RC | CONN HEADER VERT 3POS 2.54MM | https://www.digikey.com/en/products/detail/sullins-connector-solutions/PREC003SAAN-RC/2774851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 | $0.42 | 1 | $0.42 | Connector Header Through Hole 3 position 0.100" (2.54mm)
2024-10-24 | 1050281001 | CONN CAM SOCKET 32POS GOLD | https://www.digikey.com/en/products/detail/molex/1050281001/3045223 | $1.90 | 1 | $1.90 | 32 (4 x 8) Pos Camera Socket Socket Gold Surface Mount
2024-10-24 | TTL-232R-RPI | USB to TTL Serial UART Cable | https://www.mouser.com/ProductDetail/FTDI/TTL-232R-RPI?qs=3tuk1l7PSbNqj0mOeA5IPw%3D%3D | $22.30 | 1 | $22.30 | USB Cables / IEEE 1394 Cables Raspberry Pi USB to TTL Serial UART Cbl
 |  |  |  |  | Order Total | $28.10
 |  |  |  |  | Spent to Date | $212.33
2024-10-24 | 1 | Revision 1 | JLCPCB |  | 5 |  | Team 54 Printed Circuit Board (X: 2635 mil Y: 2025 mil)
2024-10-28 | BOB-16912 | FLiR Lepton Breakout Board V2 | https://www.sparkfun.com/products/16912 | $51.35 | 1 | $51.35 | Camera Development Tools FLiR Lepton Breakout Board V2
 |  |  |  |  | Order Total | $51.35
 |  |  |  |  | Spend to Date | $263.68
2024-11-08 | ESP32-S3-WROOM-1-N16 | RF TXRX MOD BT WIFI PCB TH SMD | https://www.mouser.com/ProductDetail/356-ESP32S3WROOM1N16 | $3.48 | 1 | $3.48 | Multiprotocol Modules SMD module, ESP32-S3, 16 MB SPI flash, PCB antenna
2024-11-08 | 105028-1001 | CONN CAM SOCKET 32POS GOLD | https://www.mouser.com/ProductDetail/538-105028-1001 | $1.89 | 1 | $1.89 | IC & Component Sockets 8.5*8.5 AUTO FOCUS C AMERA SOCKET ASSY
2024-11-08 | TYA40121R0M-10 | 1 uH Inductor | https://www.mouser.com/ProductDetail/Laird-Performance-Materials/TYA40121R0M-10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 | $0.21 | 10 | $2.06 | Power Inductors - SMD 1uH 3.8A 20% Wire Wound
 |  |  |  |  | Order Total | $7.43
 |  |  |  |  | Spend to Date | $271.11
2024-11-15 |  | GlobTek Inc. Battery Pack Lithium Polymer 3.7 V | https://www.digikey.com/en/products/detail/globtek-inc/BL0750F5030481S1PCTC/16515787 | $7.29 | 3 | $21.87 | 3.7 V Lithium Polymer Battery Pack
 |  |  |  |  | Order Total | $21.87
 |  |  |  |  | Spend to Date | $292.98

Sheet: 404
Order Date | Part Number | Item Name | Location to Buy From | Cost per Part | Quantity | Total Cost | Item Description
2025-01-15 | MJTP1243 | SWITCH TACTILE SPST-NO 0.05A 12V | https://www.digikey.com/en/products/detail/apem-inc/MJTP1243/1798039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 | $0.36 | 10 | $3.63 | Tactile Switch SPST-NO Top Actuated Through Hole
2025-01-15 | PREC003SAAN-RC | CONN HEADER VERT 3POS 2.54MM | https://www.digikey.com/en/products/detail/sullins-connector-solutions/PREC003SAAN-RC/2774851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 | $0.31 | 4 | $1.24 | Connector Header Through Hole 3 position 0.100" (2.54mm)
2025-01-15 | ESP32-S3-WROOM-1-N16 | RF TXRX MOD BT WIFI PCB TH SMD | https://www.mouser.com/ProductDetail/356-ESP32S3WROOM1N16 | $3.48 | 4 | $13.92 | Multiprotocol Modules SMD module, ESP32-S3, 16 MB SPI flash, PCB antenna
2025-01-15 | 105028-1001 | CONN CAM SOCKET 32POS GOLD | https://www.digikey.com/en/products/detail/molex/1050281001/3045223?s=N4IgTCBcDaIIwAYCsCwA4C0iFxAXQF8g | $1.60 | 4 | $6.40 | IC & Component Sockets 8.5*8.5 AUTO FOCUS C AMERA SOCKET ASSY
2025-01-15 | 296-50407-1-ND | IC REG BUCK ADJ 1A SOT5X3 | https://www.digikey.com/en/products/detail/texas-instruments/TLV62568ADRLR/9343350?_gl=1*p9x34z*_up*MQ.. | $0.11 | 25 | $2.83 | Buck Switching Regulator IC Positive Adjustable 0.6V 1 Output 1A
2025-01-15 | C1206Y104K9RACTU | CAP CER 0.1UF 6.3V X7R 1206 | https://www.digikey.com/en/products/detail/kemet/C1206Y104K9RACTU/5879215 | $0.36 | 20 | $7.16 | 0.1 µF ±10% 6.3V Ceramic Capacitor X7R 1206 (3216 Metric)
2025-01-15 | ERJ-8ENF1002V | RES SMD 10K OHM 1% 1/4W 1206 | https://digikey.com/en/products/detail/panasonic-electronic-components/ERJ-8ENF1002V/89059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 | $0.09 | 10 | $0.87 | 10 kOhms ±1% 0.25W, 1/4W Chip Resistor 1206 (3216 Metric) Automotive AEC-Q200 Thick Film
2025-01-15 | RC1206FR-07100KL | RES 100K OHM 1% 1/4W 1206 | https://www.digikey.com/en/products/detail/yageo/RC1206FR-07100KL/728492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 | $0.02 | 10 | $0.17 | 100 kOhms ±1% 0.25W, 1/4W Chip Resistor 1206 (3216 Metric) Moisture Resistant Thick Film
2025-01-15 | 12101C475K4T2A | CAP CER 4.7UF 100V X7R 1210 | https://www.mouser.com/ProductDetail/KYOCERA-AVX/12101C475K4T2A?qs=HXFqYaX1Q2wD22%252BbfTAf%252Bg%3D%3D | $0.48 | 10 | $4.77 | 4.7 µF ±10% 100V Ceramic Capacitor X7R 1210 (3225 Metric)
2025-01-15 | RG3216P-2003-B-T5 | RES SMD 200K OHM 0.1% 1/4W 1206 | https://www.digikey.com/en/products/detail/susumu/RG3216P-2003-B-T5/1273890 | $0.28 | 10 | $2.83 | 200 kOhms ±0.1% 0.25W, 1/4W Chip Resistor 1206 (3216 Metric) Anti-Sulfur, Automotive AEC-Q200 Thin Film
2025-01-15 | ERJ-P14F4533U | RES SMD 453K OHM 1% 1/2W 1210 | https://www.mouser.com/ProductDetail/Panasonic/ERJ-P14F4533U?qs=Zyl8A9hlmJrh0WpXEckRqw%3D%3D | $0.13 | 10 | $1.29 | 453 kOhms ±1% 0.5W, 1/2W Chip Resistor 1210 (3225 Metric) Automotive AEC-Q200, Pulse Withstanding Thick Film
2024-01-15 | 2 | Revision 2 | JLCPCB |  | 5 |  | Team 54 Printed Circuit Board (X: 2635 mil Y: 2025 mil)
 |  |  |  |  | Order Total | $45.11
 |  |  |  |  | Spend to Date | $338.09
 |  |  |  |  | Remaining Budget | -$38.09
2025-02-03 | AGC1206X7R500-105KNE-CT | Auto Grade Capacitor,1206,X7R,50 | https://www.digikey.com/en/products/detail/venkel/AGC1206X7R500-105KNE-CT/21344697 | $0.17 | 10 | $1.65 | 1 µF ±10% 50V Ceramic Capacitor X7R 1206 (3216 Metric)
 |  |  |  |  | Order Total | $1.65
 |  |  |  |  | Spend to Date | $339.74
 |  |  |  |  | Remaining Budget | -$39.74
2025-02-10 | WM1744-ND | PICOBLADE 1.25 | https://www.digikey.com/en/products/detail/molex/0530480410/242866?gad_source=1 | $0.29 | 10 | $2.88 | Connector Header Through Hole, Right Angle 4 position 0.049" (1.25mm)
 |  |  |  |  | Order Total | $2.88
 |  |  |  |  | Spend to Date | $342.62
 |  |  |  |  | Remaining Budget | -$42.62
2025-02-18 | PPPC102LFBN-RC | CONN HDR 20POS 0.1 GOLD PCB | https://www.digikey.com/en/products/detail/sullins-connector-solutions/PPPC102LFBN-RC/807245 | $1.20 | 4 | $4.80 | 20 Position Header Connector 0.100" (2.54mm) Through Hole Gold
2025-02-18 | C1206Y104K9RACTU | CAP CER 0.1UF 6.3V X7R 1206 | https://www.digikey.com/en/products/detail/kemet/C1206Y104K9RACTU/5879215 | $0.35 | 20 | $6.94 | 0.1 µF ±10% 6.3V Ceramic Capacitor X7R 1206 (3216 Metric)
2025-02-18 | GRM21BR60J226ME39L | CAP CER 22UF 6.3V X5R 0805 | https://www.digikey.com/en/products/detail/murata-electronics/GRM21BR60J226ME39L/586711 | $0.19 | 20 | $3.72 | 22 µF ±20% 6.3V Ceramic Capacitor X5R 0805 (2012 Metric)
2025-02-18 | B0CDVWC6C7 | ABS Plastic Sheet 8" x 12" x 0.060" | https://www.amazon.com/KAITELA-Plastic-Thermoplastic-Crafts-Projects/dp/B0CDVWC6C7 | $8.99 | 1 | $8.99 | Thick Black Moldable Flexible Thermoplastic Panel 1/16" Thick (1.5mm) for Craft Projects, Robotics Competitions - Textured & Smooth Surface, Pack of 2
2025-02-18 | 3 | Revision 3 | JLCPCB |  | 5 |  | Team 54 Printed Circuit Board (X: 2365 mil Y: 1675 mil )
 |  |  |  |  | Order Total | $24.45
 |  |  |  |  | Spend to Date | $364.19
 |  |  |  |  | Remaining Budget | -$64.19
2025-03-17 | 32-806 | IR Window Material | https://www.edmundoptics.com/p/6quot-x-6quot-translucent-ir-material-window/2593/ | $29.00 | 1 | $29.00 | 6" x 6" and translucent sheet of IR window material
2025-03-17 | LBBCLUSB-2 | 3.7 V Lithium Battery Balance Charging Line | https://www.amazon.com/outstanding-Lithium-Charging-Connector-Aircraft/dp/B08GBVHYJP | $6.68 | 1 | $6.68 | E-outstanding 3.7V Lithium Battery Balance Charging Line USB to XH2.54 Connector and XH2.54 to JST Convert Line for RC Aircraft Drone
2025-03-17 | 1939-BL0750F5030481S1PCTC-ND | GlobTek Inc. Battery Pack Lithium Polymer 3.7 V | https://www.digikey.com/en/products/detail/globtek-inc/BL0750F5030481S1PCTC/16515787 | $7.19 | 3 | $21.57 | 3.7 V Lithium Polymer Battery Pack
 |  |  |  |  | Order Total | $57.25
 |  |  |  |  | Spend to Date | $421.44
 |  |  |  |  | Remaining Budget | -$121.44
2025-04-07 | 1939-BL0750F5030481S1PCTC-ND | GlobTek Inc. Battery Pack Lithium Polymer 3.7 V | https://www.digikey.com/en/products/detail/globtek-inc/BL0750F5030481S1PCTC/16515787 | $5.98 | 10 | $59.80 | 3.7 V Lithium Polymer Battery Pack
 |  |  |  |  | Order Total | $59.80
 |  |  |  |  | Spend to Date | $481.24
 |  |  |  |  | Remaining Budget | -$181.24

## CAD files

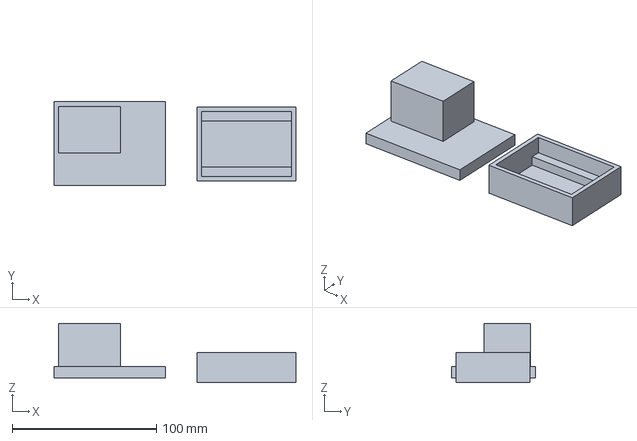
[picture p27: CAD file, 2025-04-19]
PCB/Hardware Encasing.3mf
168.0 x 58.0 x 41.3 mm

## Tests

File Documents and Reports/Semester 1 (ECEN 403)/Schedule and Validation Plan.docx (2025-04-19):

Remote Viewing within a High Voltage Apparatus

Blake Bagley, Julia Garcia, Erica Mathew

Schedule and Validation

REVISION – Draft

24 September 2024

Schedule and Validation

for

Remote Viewing within High Voltage Apparatus

Schedule:

Work | End date | Owner | Staus | Date Completed
Concept of Operation | 9/15/2024 | All
Functional System Requirements | 9/26/2024 | All
IInterface Control Document | 9/26/2024 | All
Project Parts Ordered | 9/24/2024 | All
Microcontroller Intro Project | 9/30/2024 | Blake
PCB Design Intro Project | 9/30/2024 | Julia
Web Application Intro Project | 9/23/2024 | Erica
Web Application Structure + Set up Firebase Project | 9/25/2024 | Erica
Design Login page and implement Firebase Authentication | 9/30/2024 | Erica
Midterm Presentation | 9/30/2024 | All
Image Recognition Training Data | 10/7/2024 | Blake
Buck Converter Design and Simulation | 10/7/2024 | Julia
Initial Microcontroller Code | | Blake
Initial PCB Designed and Ordered | 10/10/2024 | Julia
Build Homepage that Displays multiple Live Video Feeds | 10/11/2024 | Erica
Initial PCB Received | 10/17/2024 | Julia
Buck Converters Tested on Breadboard | 10/17/2024 | Julia
Image Recognition Complete | 10/21/2024 | Blake
Design +Implement backend integration for fetching video feeds | 10/21/2024 | Erica
Status Update Presentation | 10/23/2024 | All
Initial PCB Complete | 10/28/2024 | Julia
Switch-State Determination for Fixed Pixels | 10/28/2024 | Blake
Switch-State Determination Complete | 11/4/2024 | Blake
Build Separate Page to view Specific Video Feed | 11/4/2024 | Erica
Create ‘Open’/’Closed’ alerts on website | 11/11/2024 | Erica
Added website features for user convenience | 11/15/2024 | Erica
Image Recognition and Switch-State Determination working together | 11/11/2024 | Blake
Final PCB Complete | 11/15/2024 | Julia
Final Presentation | 11/20/2024 | All
Finish Subsystem Presentation | 11/24/2024 | All
Subsystem Demo | 11/26/2024 | All
Work on report | 11/30/2024 | All
Finish Final Report | 12/3/2024 | All
Final Report | 12/5/2024 | All

Subsystem | Task | Detail | Data | Pass/Fail
Thermal Sensor (Julia) | Provide Power | Input Voltage reads ~3.7 V
| | Microcontroller turns on
| | Sensor turns on
| Buck Converters | Output to VDDC reads ~1.26 V
| | Output to VDD reads ~2.88 V
| | Output to VDDIO reads ~3.1 V
| | Output to ESP32 reads ~3.6 V
| | Receiving signal from microcontroller
| Sensor Sending Video | Signal is coming from output
Microcontroller (Blake) | Image Recognition Accuracy (90%) | Close and centered switch
| | Far and centered switch
| | Close and uncentered switch
| | Far and uncentered switch
| Switch-State Determination Accuracy (90%) | Close and centered switch
| | Far and centered switch
| | Close and uncentered switch
| | Far and uncentered switch
| Receiving Video from Sensor
| Sending Video to Website
Website Application (Erica) | Receiving Video | If video is not fetched after 30 seconds, an error will appear
| | Video should output with no more than 5 second delay
| | Video should be of correct vertical tower
| Login-in System | Login with correct credentials
| | Login with incorrect credentials
| Search Bar | Search bar directs user to the proper video stream
| Video Display Page | Overview Page that displays multiple video streams
| | Video streams in overview page are clickable to redirect user to zoomed in video feed on a different page

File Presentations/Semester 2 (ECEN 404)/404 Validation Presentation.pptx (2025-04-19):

## Team 54: Remote Thermal Viewing within High Voltage Validation Presentation Blake Bagley, Julia Garcia, Erica Mathew Sponsor: Powell Industries TA: Vishwam Raval


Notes: Michelle

## PCB Validation

## Microcontroller Validation

## Login + Registration Pages

Login Page for users to log into existing profiles

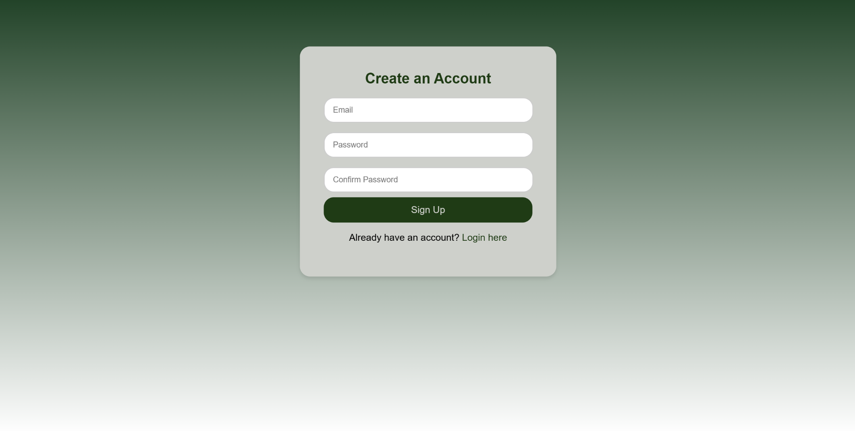
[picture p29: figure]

FireBase Authentication allows users to create and store profiles in their database

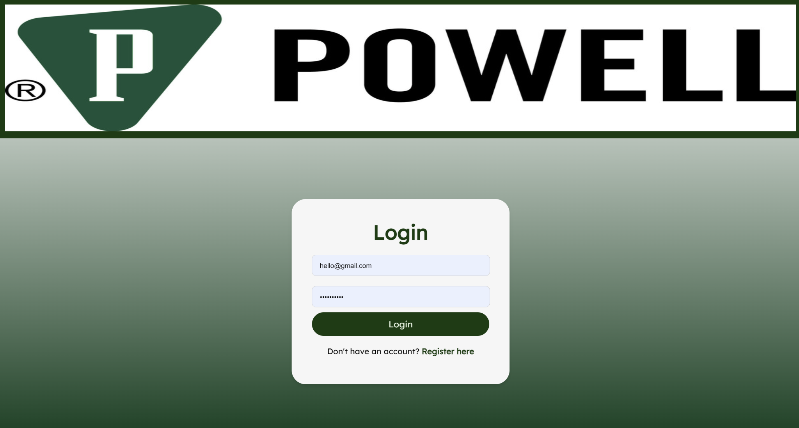
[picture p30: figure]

Registration Page for users to create profile

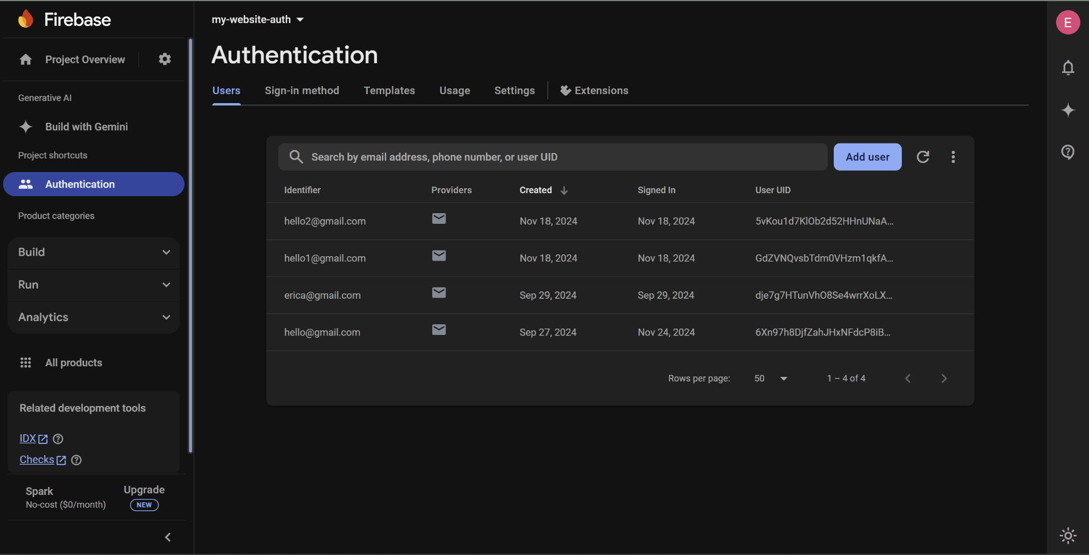
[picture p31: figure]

## Map Builder

- List of MODEL IDs represented as blocks
- Use Interact.js to enable smooth drag/dropping between 2 dropzones (model-list and map-area)
- Saves current layout to local storage
- Layout is only cleared once when ‘reset’ button is clicked
- Clicking on blocks 001 or 002 will direct user to video page of that specific MODEL ID passed as a URL parameter

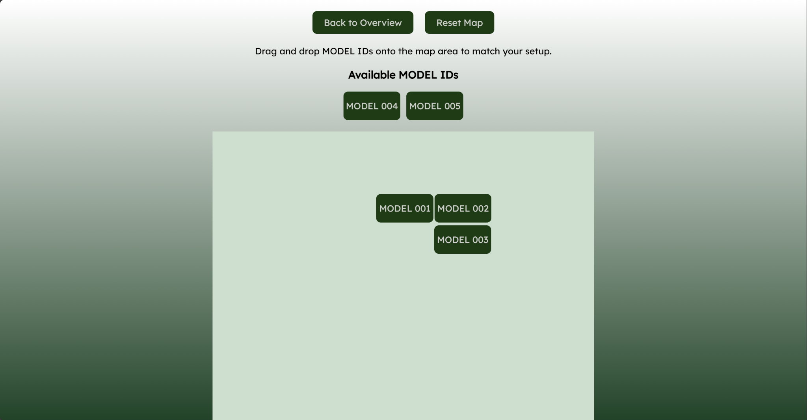
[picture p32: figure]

Allows users to build a custom layout that matches their physical switchgear setup by dragging and dropping blocks that represent model ID. By clicking on a block it will direct the user to its specific video stream.

## Video Streaming

## Validation + 404 Integration

3.2.1.4 | Receiving Video | If no video stream is displayed on website, an error message should be outputted to screen. Video should be of correct vertical tower | Confirm the correct file is linked to its respective MODEL ID (either 001 or 002). 003-005 should display error message. | PASS | Erica Mathew
3.2.1.1 | Login-in System | Login with correct credentials and fail with incorrect credentials | Have user create different login credentials to check if they are stored in firebase | PASS | Erica Mathew
3.2.1.1 | Search Bar | Search bar redirects user to the proper video stream | Have user type different ID numbers to test search bar functionality | PASS | Erica Mathew
3.2.1.4 | Video Display Page | Overview Page that displays multiple video streams. Video streams in overview page are clickable to redirect user to zoomed in video feed on a different page | Send different video live streams and have user try to access all of them | PASS | Erica Mathew

After integrations with microcontroller:
Server Side:
- Receives live images from microcontroller
- Broadcast to client via websockets

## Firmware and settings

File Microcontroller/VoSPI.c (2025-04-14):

//Blake Bagley Remote Viewing System Code

/*----------------------------------------------------------------
This code has three key functions for the system:

1. Read picture data from the thermal imager

2. Use image processing to determine if switch is open or closed

3. Send both data to the desired website
----------------------------------------------------------------*/

//
#include <stdio.h>
#include <math.h>
#include "sdkconfig.h"
#include "esp_wifi.h"
#include "nvs_flash.h"
#include "driver/spi_master.h"
#include "esp_log.h"
#include <string.h>
#include "driver/gpio.h"
#include "esp_rom_sys.h"
#include "esp_heap_caps.h"
#include "esp_heap_caps_init.h"
#include "esp_http_client.h"
#include "esp_netif.h"
#include "esp_err.h"
#include "esp_event.h"
#include <float.h>


//GPIO Pin Definitions
#define CS_PIN      39//9 //     //Brown Stripe
#define SCLK_PIN    36//39//     //Pink
#define MOSI_PIN    35//35//     //Brown
#define MISO_PIN    37//14//     //Purple Stripe

//WiFi and HTTP definitions
#define SSID "BBagley"
#define PASS "TAMU24!$"
#define TAG "HTTP_CLIENT"


void app_main(void)
{
    
    printf("Initializing: \n");






//---------------SPI CONFIGURATION--------------------//

    spi_device_handle_t Lepton;

    spi_bus_config_t pins = { //GPIO pins
        .mosi_io_num = MOSI_PIN,
        .miso_io_num = MISO_PIN,
        .sclk_io_num = SCLK_PIN,
        .quadwp_io_num = -1,
        .quadhd_io_num = -1};

    
    spi_device_interface_config_t lepton_config = { //Communication configuration
        .command_bits = 0,
        .address_bits = 0,
        .dummy_bits = 0,
        .clock_speed_hz = 20000000,                 //20 MHz
        .duty_cycle_pos = 128,                      // 50% duty cycle
        .mode = 3,                                  //VSPI
        .spics_io_num = CS_PIN,                     //CS
        .queue_size = 1};

    spi_bus_initialize(SPI3_HOST, &pins, SPI_DMA_CH_AUTO);

    spi_bus_add_device(SPI3_HOST, &lepton_config, &Lepton);

//----------------------------------------------------//


//-------------------------------SET UP WIFI----------------------------------------//


    void wifi_handler(void *event_handler_arg, esp_event_base_t event_base, int32_t event_id, void *event_data)
    {
        switch (event_id)
        {
        case WIFI_EVENT_STA_CONNECTED:
            printf("CONNECTED \n");
            break;
        case WIFI_EVENT_STA_DISCONNECTED:
            printf("DISCONNECTED from Wi-Fi. Retrying...\n");
            esp_wifi_connect();  // Attempt reconnection if disconnected
            break;
        case WIFI_EVENT_STA_AUTHMODE_CHANGE:
            printf("Authentication mode changed.\n");
            break;
        default:
            break;
        }
    }

   nvs_flash_init();

   esp_netif_init();					
   esp_event_loop_create_default();
   esp_netif_create_default_wifi_sta();
   
   //Initialize WiFi
   wifi_init_config_t wifi_initialize_info = WIFI_INIT_CONFIG_DEFAULT();
   esp_wifi_init(&wifi_initialize_info);
   esp_event_handler_register(WIFI_EVENT, ESP_EVENT_ANY_ID, wifi_handler, NULL);

   esp_wifi_set_mode(WIFI_MODE_STA); // Set to Access Point
   
   //Set WiFi Configurations
   wifi_config_t WiFi_Info = {.sta = {.ssid = SSID, .password = PASS}}; 
   esp_wifi_set_config(WIFI_IF_AP, &WiFi_Info);

   esp_wifi_start(); //Start WiFi

   esp_wifi_connect();
   printf("Connecting...");

   



//----------------------------------------------------------------------------------//


//------------------------------SET UP HTTP------------------------------------------//

void http_event_handler(esp_http_client_event_t *evt) {
    switch (evt->event_id) {
        case HTTP_EVENT_ERROR:
            ESP_LOGI(TAG, "HTTP_EVENT_ERROR");
            break;
        case HTTP_EVENT_ON_CONNECTED:
            ESP_LOGI(TAG, "HTTP_EVENT_ON_CONNECTED");
            break;
        case HTTP_EVENT_HEADER_SENT:
            ESP_LOGI(TAG, "HTTP_EVENT_HEADER_SENT");
            break;
        case HTTP_EVENT_ON_HEADER:
            ESP_LOGI(TAG, "HTTP_EVENT_ON_HEADER, key=%s, value=%s", evt->header_key, evt->header_value);
            break;
        case HTTP_EVENT_ON_DATA:
            if (!esp_http_client_is_chunked_response(evt->client)) {
                ESP_LOGI(TAG, "HTTP_EVENT_ON_DATA: %.*s", evt->data_len, (char *)evt->data);
            }
            break;
        case HTTP_EVENT_ON_FINISH:
            ESP_LOGI(TAG, "HTTP_EVENT_ON_FINISH");
            break;
        case HTTP_EVENT_DISCONNECTED:
            ESP_LOGI(TAG, "HTTP_EVENT_DISCONNECTED");
            break;
        default:
            break;
    }
    
}

vTaskDelay(5000 / portTICK_PERIOD_MS);


printf("Initialized: \n");
printf("GOOOOOOOOOOOOOOOOO!!!!!!!!!!!!!!!\n\n");

//---------------Switch State Determination Variables----------------//
float rowSum = 0;                                               //sum of pixel values in a row
float frameAvg = 0;                                             //average value of pixels in a frame


int checkSum = 0;                                               //sum of pixel vaues in the window of check
float checkAvg = 0;                                             //average value of pixels in the window of check

float minHeat = FLT_MAX;                                        //initialized to first pixel value
float maxHeat = FLT_MIN;

float currHeat = 0;                                             //heat value of current pixel

//-------------------------------READ FRAME----------------------------------------//
/*
    This section works in this order:
    1. The first packet of the frame will be read. If it is a discard packet and/or not the starting packet,
            the code will loop until it reads the first packet correctly and store it's value in the frame array.

    2. Once it reads the first packet in, a loop of length 60 will run using the same checks and reads including a
            segment check. If the segment or packet IDs read bad, the storing of the frame is reset. For each segment,
            when one is stored the code will track all of the segments that have been stored into the frame.

    3. Once all segments have been read, the reading of the frame will end.
*/

while (true)
{
    char* packet = (char*)malloc(164 * sizeof(char));                       //buffer for video packet

    char **frame = malloc(240 * sizeof(char*));     //Total Frame Data
    
    for (int i = 0; i < 240; i++) {
        frame[i] = malloc(164 * sizeof(char));
    }


    char* Nframe = malloc(120 * 160 * sizeof(char)); //Total Normalized Frame Data
    
    vTaskDelay(250 / portTICK_PERIOD_MS);
    bool segment[4] = {false};                                              //array telling if a segment as been stored into frame

    spi_transaction_t receive;
    memset(&receive, 0, sizeof(receive));   //set buffer to default settings
    receive.length = 164 * 8;               //size of buffer
    receive.rx_buffer = packet;             //sets buffer to be the stored packet
    
    int index = 0; // index of frame to be read
    int error = 0;
    while(segment[0] != true || segment[1] != true || segment[2] != true || segment[3] != true){

        int segmentIndex = 0;                                       //index of current segement
        bool badSegment = false;
        if(error >= 1000){
            vTaskDelay(1500 / portTICK_PERIOD_MS);
            error = 0;
        }
        printf(" Packet ID: %d %d %d %d %d \n", (int)packet[0], (int)packet[1], (int)packet[2], (int)packet[3], (int)packet[4]);
        vTaskDelay((rand() % 8) / portTICK_PERIOD_MS);
        spi_device_transmit(Lepton, &receive);                      //read for first row in segment
        error++;
        
        if(((int)packet[0] != 15 && (int)packet[0] != 31 && (int)packet[0] != 63 && (int)packet[0] != 127 && (int)packet[0] != 255) && (int)packet[1] == 0){ //checks for discard frames            

            memcpy(frame[index], packet, 164 * sizeof(char));       //store first row
            index++;               
            segmentIndex++;

            while(segmentIndex < 60)                                //stores the rest of the segment
            {   
                spi_device_transmit(Lepton, &receive);              //reads for rows
                if(((int)packet[0] != 15 && (int)packet[0] != 31 && (int)packet[0] != 63 && (int)packet[0] != 127 && (int)packet[0] != 255) && (int)packet[1] < 60){ //checks for discard frames
                    
                    if(((int)packet[1] != segmentIndex && ((int)packet[1] != 0  || segmentIndex != 60)) && !badSegment){                            
                        //printf("BAD FRAME!!! %d != %d\n\n", (int)packet[1], segmentIndex);                       
                    }

                    if(segmentIndex == 20){                         //Checks which segment is read
                        //printf("SEGMENT ID: %d , %d\n\n", (int)packet[0], (int)packet[1]);

                        if((int)packet[0] == 16){                   // Segment 1
                            segment[0] = true;
                        }
                        else if((int)packet[0] == 32){              // Segment 2
                            segment[1] = true;
                        }
                        else if((int)packet[0] == 48){              // Segment 3
                            segment[2] = true;
                        }
                        else if((int)packet[0] == 64){              // Segment 4
                            segment[3] = true;
                        }
                        else{                                       // Bad Segment
                            badSegment = true;
                        }
                    }
                    
                    memcpy(frame[index], packet, 164 * sizeof(char)); //stores rows
                    index++;
                    segmentIndex++;                       
                }
            }
            if(badSegment){                                           //resets frame for bad reading
                index = 0;
                memset(segment, false, sizeof(segment));
            }
        }
    }
    index = 0;
    memset(segment, false, sizeof(segment));

//-----------------------------------------------------------------------//
// Segment ID Test
//for(int i = 0; i < 163; i += 2){
//    if(i <= 2){
//        printf("ID %d: %d , %d \n", i, (int)frame[20][i], (int)frame[20][i+1]);
//    }
//    else{
//        printf("PIXEL %d: %d , %d \n", (i/2)-2, (int)frame[20][i], (int)frame[20][i+1]);
//    }
//    
//}



//------------------------Switch State Determination---------------------//
/*
1. The first thing done is the code will sift through the stored frame and determine the maximum and minimum 
    pixel values on the entire frame.

2. Then, the code will use the values found in the previous step to create a normalized version of the frame
    having the values range from 0 to 255.

3. Finally, the code will find the average intensity of the entire frame and the average intensity of an
    area of pixels where the contact of the switch can be located. It will then compare the two averages
    to determine if the switch is in one state or the other.
*/



rowSum = 0;                                                 //sum of pixel values in a row
frameAvg = 0;                                             //average value of pixels in a frame


checkSum = 0;                                               //sum of pixel vaues in the window of check
checkAvg = 0;                                             //average value of pixels in the window of check

minHeat = FLT_MAX;    
maxHeat = FLT_MIN;

currHeat = 0;                                             //heat value of current pixel


//Find MIN and MAX of Pixel intensity
for(int j = 0; j < 240; j += 1){
    for(int i = 4; i < 163; i += 2){
        currHeat = ((float)frame[j][i] * 128) + (float)frame[j][i+1];   //converts pixel data to one float value
        if(currHeat <= minHeat){                                         //finds minimum
            minHeat = currHeat;
        }
        if(currHeat >= maxHeat){                                         //finds maximum
            maxHeat = currHeat;
        }
    }
}


int side = 0; //0 means left
int sideCheck = 0; //checks which side the current packet is on
uint8_t newPixel = 0;
float pixelF = 0; 
int order = 0;

//Converts original frame data to 8-bit numbers
for(int j = 0; j < 240; j += 1){
    for(int i = 4; i < 163; i += 2){
        currHeat = ((float)frame[j][i] * 128) + (float)frame[j][i+1];                       //converts pixel data to one float value
        pixelF = (currHeat - minHeat) * (255/(maxHeat-minHeat));
        newPixel = (uint8_t)pixelF;

        if(sideCheck == 0){
            Nframe[order] = newPixel;
            //Nframe[j/2][(i-4)/2] = newPixel;
                
            side = 1;
        }
        else if(sideCheck == 1){     
            Nframe[order] = newPixel;
            //Nframe[(j-1)/2][((i-4)/2)+80] = newPixel; //converts values to range from 0-255 (right side of row)
            
            side = 0;
        }
        order++;
    }
    sideCheck = side; 
}


// Average for frame
for(int j = 0; j < 120 * 160 ; j += 1){
    rowSum += Nframe[j];
}
frameAvg = rowSum/(160 * 120);


// Average for window of check
int pixel = 0;                          //# of pixels in window
for(int j = 23; j < 54 ; j += 1){ //j = row, i = col
    for(int i = 31; i < 63; i += 1){
        //checkSum += Nframe[j][i];       //adds all pixel values
        checkSum += Nframe[(160 * j) + i];
        pixel++;
    }
}

for(int j = 17; j < 49 ; j += 1){ //j = row, i = col
    for(int i = 21; i < 53; i += 1){
        if( (i == 21 || i == 52)  || (j == 17 || j == 48)){
            Nframe[(160 * j) + i] = 255;
        }

    }
}
checkAvg = checkSum/(pixel);            //calculates average

printf("Frame Average: %f \n", frameAvg);
printf("Check Average: %f \n", checkAvg);




//--------------------------------------------------------------------//

//-------Prints values for MATLAB test--------------//
//order = 0;
//for(int i = 0; i < 120 ; i++){
//    for(int j = 0; j < 160; j++){
//        printf("%d ", (int)Nframe[order]);
//        order++;
//    }
//        printf("; \n");                
//}


//------------------------Website Communication---------------------//
/*
1. The microcontroller will set the website as the desired desitnation and send headers of info
like the switch-state determination and the image data
*/
esp_http_client_config_t config_post = {
    .host = "10.247.214.208",
    .port = 3000,
    .method = HTTP_METHOD_POST,
    .cert_pem = NULL,
    .event_handler = http_event_handler,
    .path = "/ping",
    .timeout_ms = 20000};

esp_http_client_handle_t client = esp_http_client_init(&config_post);

esp_http_client_set_post_field(client, Nframe , 160 * 120 * sizeof(char));
esp_http_client_set_header(client, "Content-Type", "application/octet-stream");


if((checkAvg-frameAvg)/(frameAvg) > .20){ //compares averages to determine switch state
    printf("SWITCH STATE 1 \n");
    esp_http_client_set_header(client, "Switch-State", "Closed");
}
else{
    printf("SWITCH STATE 2 \n");
    esp_http_client_set_header(client, "Switch-State", "Open");
}


esp_http_client_perform(client);
esp_http_client_cleanup(client);


//-------------------------Freeing Memory-----------------------------//
for (int i = 0; i < 240; i++) { //Frees Frame Storage
    free(frame[i]);
}
free(frame);

free(Nframe);                   //Frees Normalized Frame Storage

free(packet);                   //Frees Packet Storage
}
vTaskDelay(500 / portTICK_PERIOD_MS);









}

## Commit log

2025-04-14 Rename ESP32 Power.SchDoc to PCB/ESP32 Power.SchDoc
    [ESP32 Power.SchDoc]
2025-04-14 Rename Project Outputs for ECEN404_Team54_PCB.zip to PCB/Project Outputs for ECEN404_Team54_PCB.zip
